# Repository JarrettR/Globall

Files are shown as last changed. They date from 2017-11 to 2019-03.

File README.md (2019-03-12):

Globall
================

### What's this?

This is a persistence-of-vision globe.

### What's that?

Persistence of vision is the phenomenon where something moving very fast appears to be an entire collection of objects. Generally involving light, it can fool our eyes into believing that we're seeing a single line of light when there's really only one, or a 2D image, when there's really only a single line of lights turning on and off quickly.

### Cool! How does that relate?

By arranging LEDs around a circle and spinning it very rapidly, an image can be created. The primary use-case of this repo is to create a globe (using green and blue LEDs), but it can easily be used for text or any other arbitrary image.

### Pictures

Mechanical, PCB, and spinning globe:

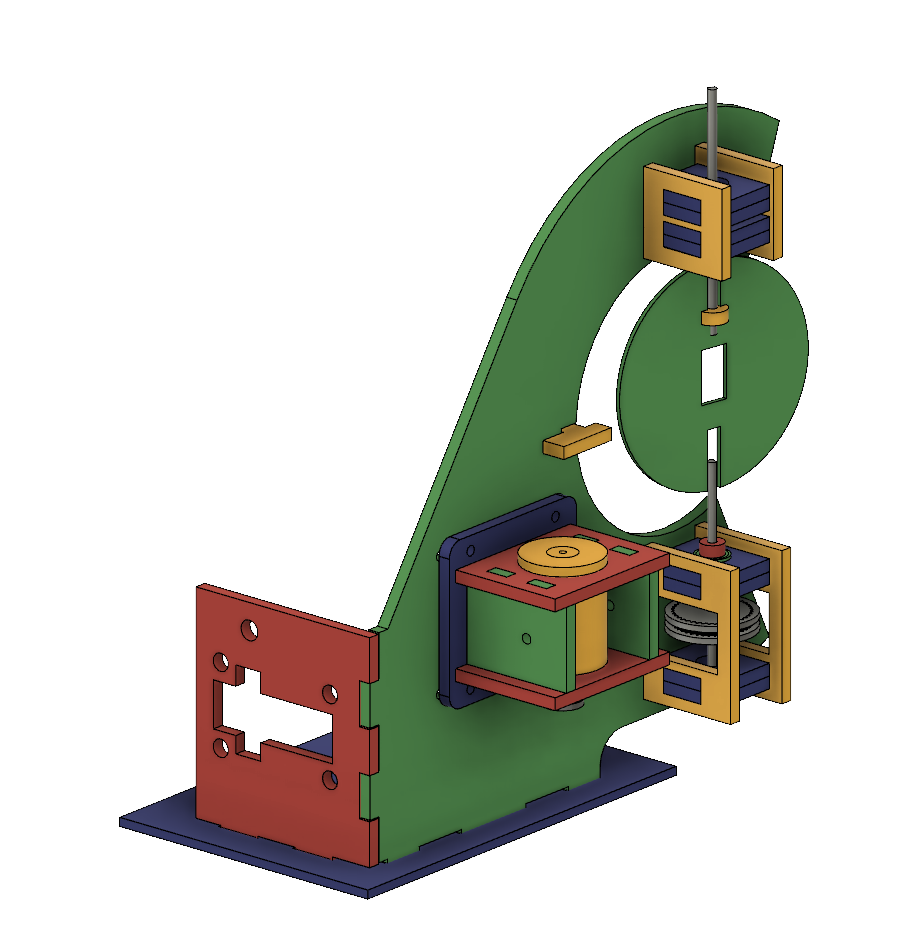
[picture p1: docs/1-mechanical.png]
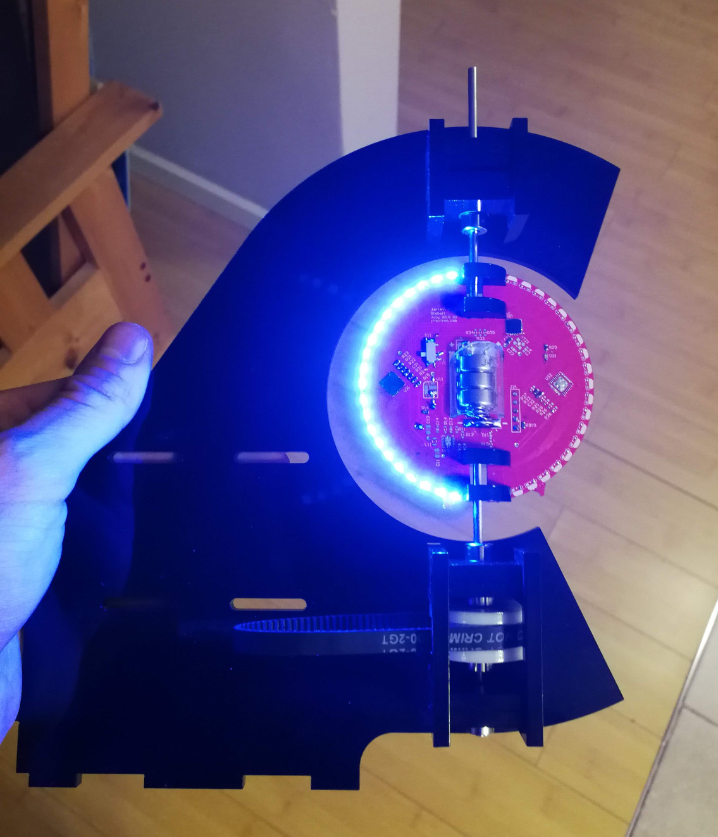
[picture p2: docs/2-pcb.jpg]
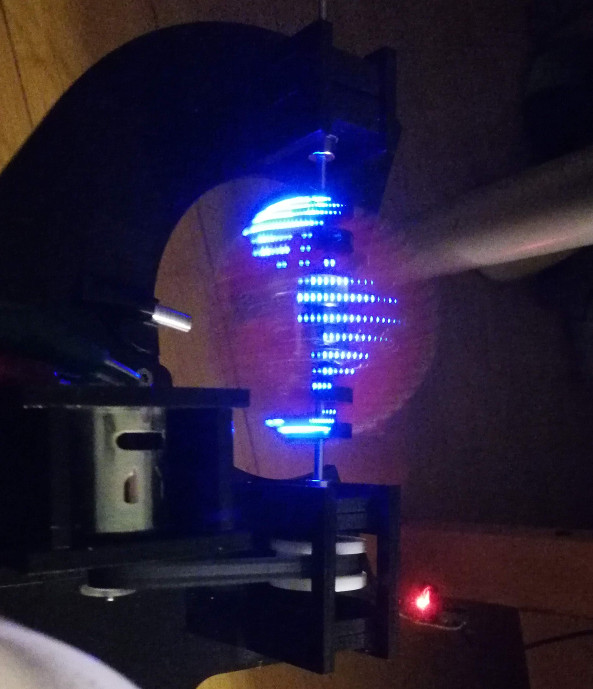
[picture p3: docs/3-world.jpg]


Pattern-making:

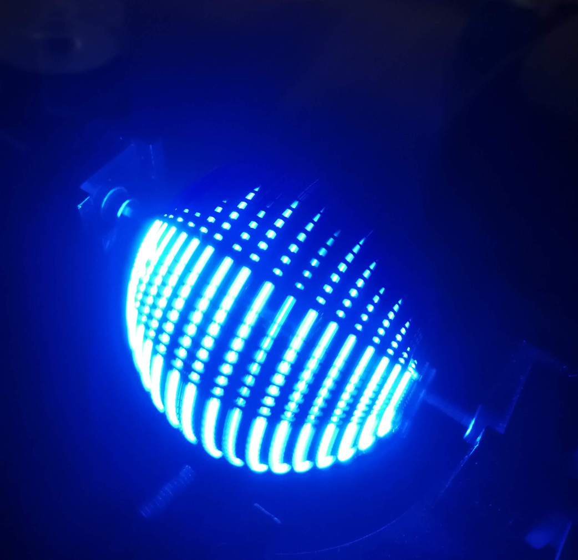
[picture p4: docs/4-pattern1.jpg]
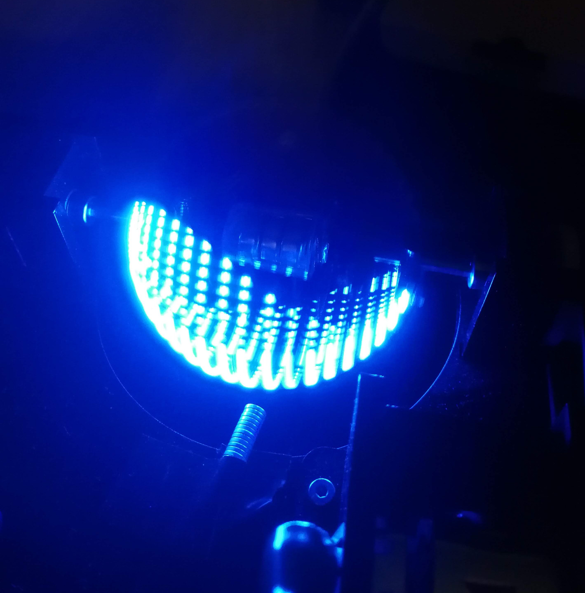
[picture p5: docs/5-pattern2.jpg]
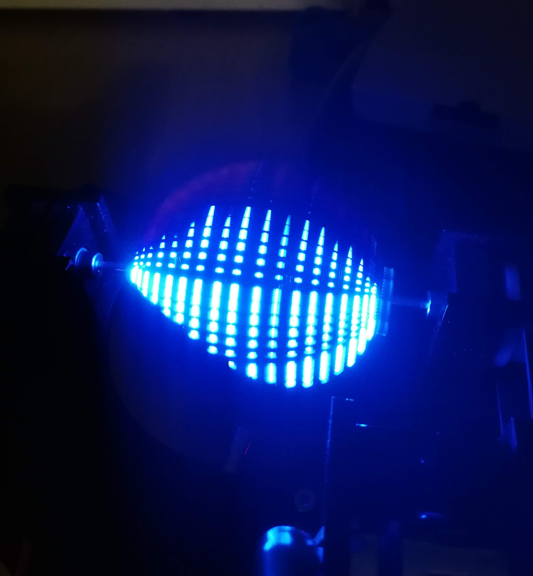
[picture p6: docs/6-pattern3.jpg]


### Status

This is under sporadic development.
The firmware is compilable, and it can generate passable images.
The PCB works, but will eventually go through a redesign. More LEDs, smaller LEDs, and a bunch of the power supply features can be stripped out.
The mechanical design has always been intended to be a minimum viable product, and is very functional. A redesign to make it prettier will eventually happen.
The image converter in the tools page might be useful for other POV systems at this change, check it out.

### Contributing

This is a (mostly) hardware project! I don't know what contributions are possible! Hardware pull requests are unlikely to be accepted, but give anything else a shot, I guess. I'm open to it.

### Useful takeaways

Check the `tools` folder for the Python tool I wrote to generate the image data. It should be fairly extentible to any projects that require displaying images programmatically.

### Further Reading

I have written a summary post about this on my website, [here](https://jrainimo.com/build/?p=1176).

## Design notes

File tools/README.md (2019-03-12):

Tools
================

## convert.py

### Usage

This is a tool that takes in image files, processes them, and then exports them into PNG, CSV, or C code formats.

First, install the only prerequisite, the Python Imaging Library:
`pip install pillow`
You might need to run that with `sudo` or as an administrator on Windows.

For this particular project, the command to generate the final files is:
` python convert.py -i World_map.png -t c -n -v -c blueMap -x 60 -y 20 -o blue `

Type `python convert.py --help` for full list of options. At present, this is the output:

```
> python convert.py --help

usage: convert.py [-h] [-x WIDTH] [-y HEIGHT] [-i INPUT] [-o OUTPUT] [-t TYPE]
                  [-n] [-c CONST] [-f] [-l] [-v]

optional arguments:
  -h, --help            show this help message and exit
  -x WIDTH, --width WIDTH
                        Pixel density horizontal
  -y HEIGHT, --height HEIGHT
                        Pixel density vertical
  -i INPUT, --input INPUT
                        Input file
  -o OUTPUT, --output OUTPUT
                        Output file, no extension
  -t TYPE, --type TYPE  Output format(csv, png, or c)
  -n, --invert          Invert pixel weight
  -c CONST, --const CONST
                        (C output only) Const var name
  -f, --fragmented      Split up data for fragmented memory
  -l, --large           Larger, 12-bit pixels
  -v, --verbose         Print out internal variables
```

This was intended to be reusable, and is fairly robust.

It should take any image format and convert it to greyscale, although different formats have not been tested exhaustively. PNG files work well.

For this project, sensible defaults (and the ones included in the firmware) are generated using `./gen.sh`

### Sample Inputs

These are some good images for testing various setups.

#### simple.png

simple

Simple, small image of multiple colours, intended to test the conversion process only.

#### scrolltest.png

scrolltest

A human-recognisable pattern to easily check correct pixel order on the physical test bench.

#### cycle.png

cycle

A similar human-recognisable pattern to the above.

#### right-align.png and left-align.png

left-align

right-align

With one of these on each side, tests the code speed and maximum input frequency.
At a comfortable speed, all LEDs on both sides will be blinking. As soon as speed increases enough that the processor is no longer able to keep up, half of one or both sides will start sticking. As the input pulses is fed in faster, the LEDs will stop working entirely.

This is a quick way to tune for "max frequency".

#### World_map.png

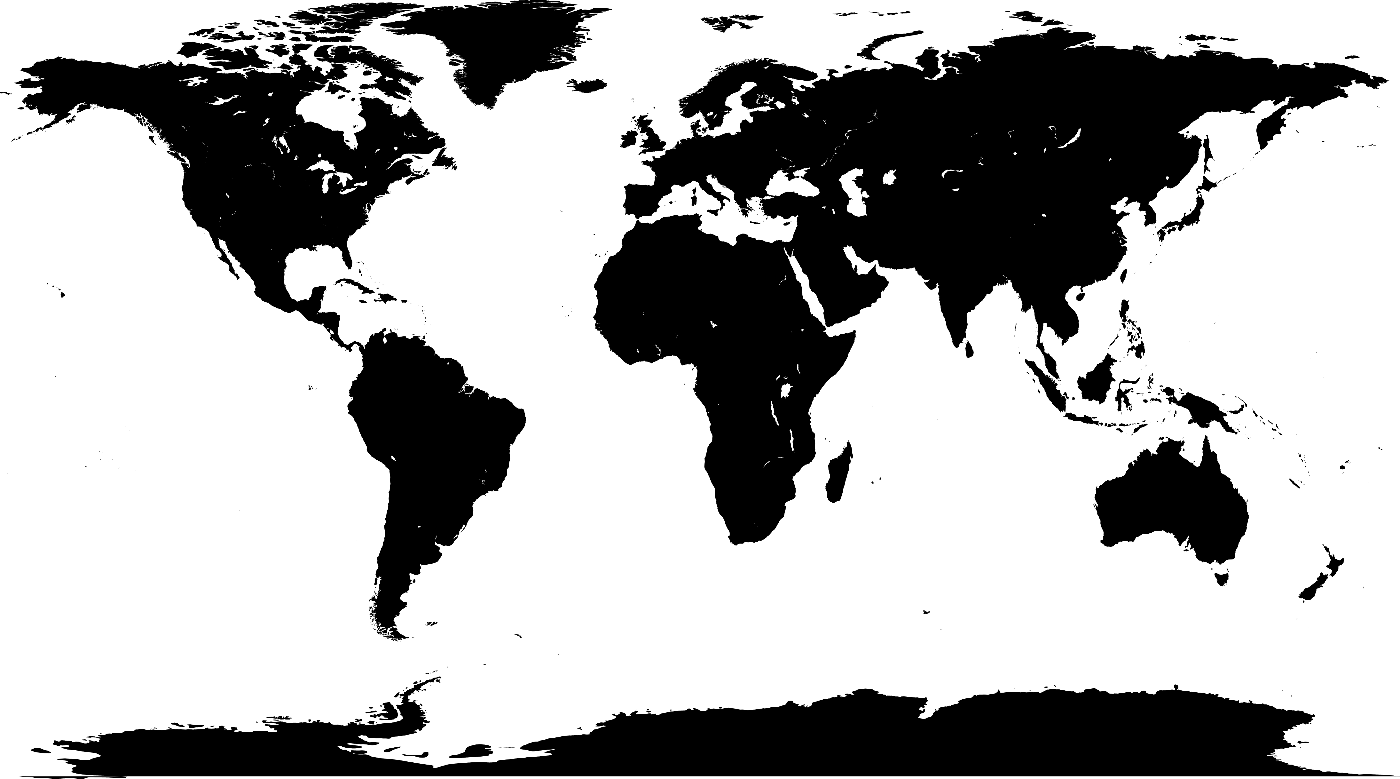
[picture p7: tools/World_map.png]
World_map


The goal.

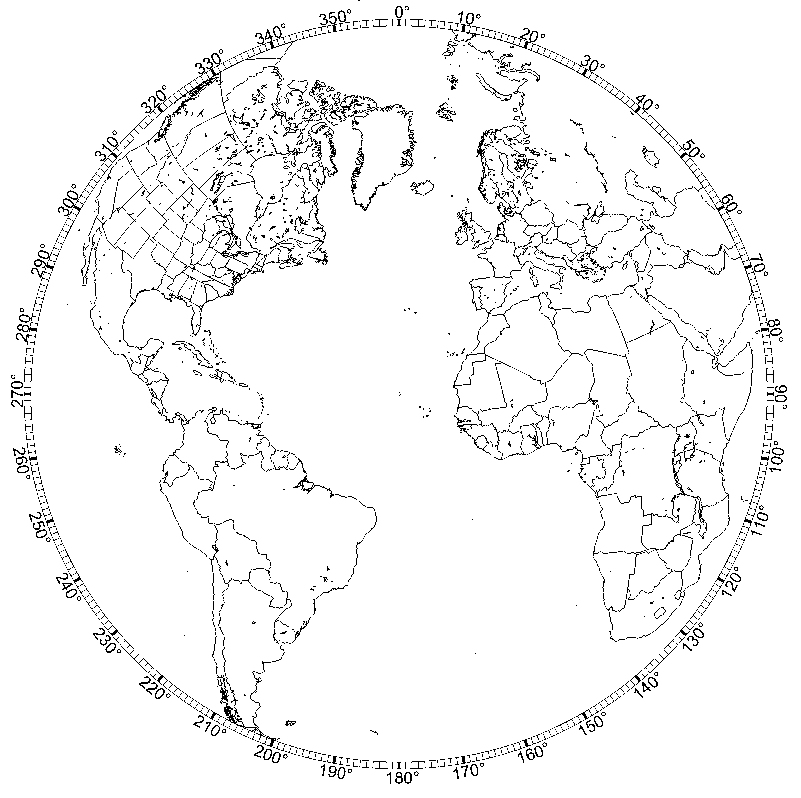
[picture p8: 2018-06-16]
Hardware/R1/AzimuthalMap2.bmp

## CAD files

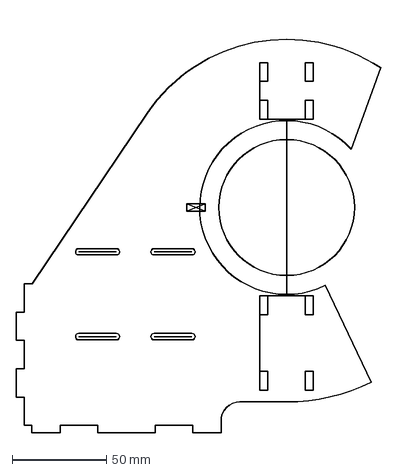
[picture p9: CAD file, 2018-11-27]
Mechanical/R1/DXFs/1 - Main Plate.dxf
193.0 x 220.9 mm

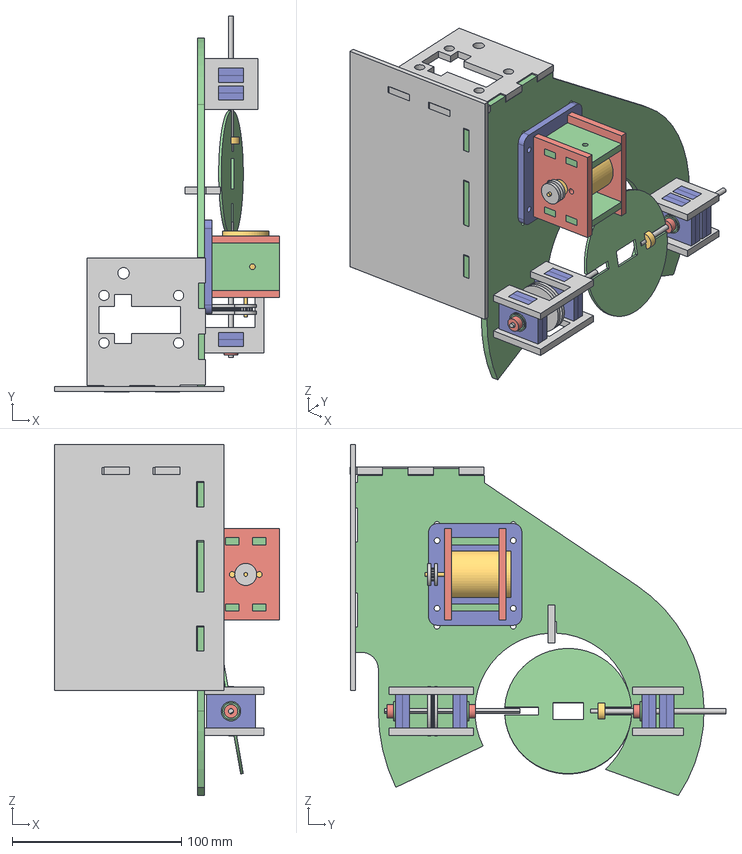
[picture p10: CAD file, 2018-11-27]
Mechanical/R1/DXFs/Main Assembly.step
132.9 x 221.9 x 207.2 mm
Bearing Side Plate x 2
Main Plate
Bearing holder x 8
Driven Pulley 40t
D-Shaft x 2
PCB
DC Motor
Motor Pulley
Motor mount plate
Motor Back Plate
Motor Bottom Plate
Motor Side Plate x 2
Bearing Long Side Plate x 2
623ZZ Flanged x 3
3mm Shaft Collar x 3
Shaft Coupler
base
Magnet Holder
Base Support

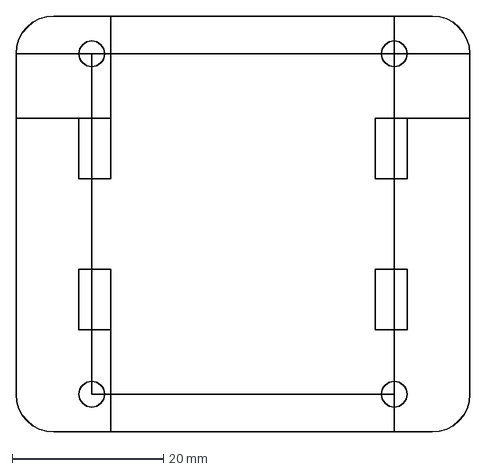
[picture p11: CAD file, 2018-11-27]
Mechanical/R1/DXFs/1 - Motor Bottom Plate.dxf
60.0 x 55.0 mm

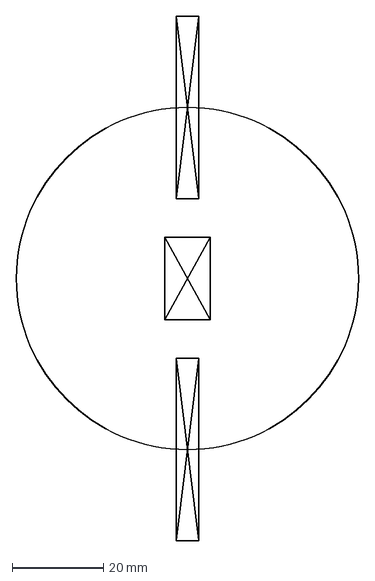
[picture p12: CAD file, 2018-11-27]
Mechanical/R1/DXFs/1 - PCB.dxf
75.0 x 115.0 mm

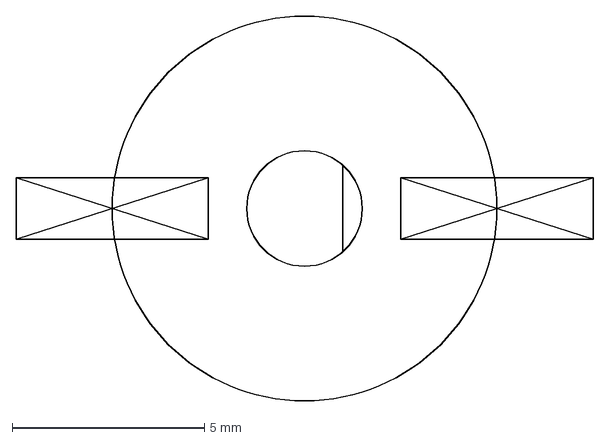
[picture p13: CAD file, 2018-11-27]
Mechanical/R1/DXFs/4 - Shaft Coupler.dxf
15.0 x 10.0 mm

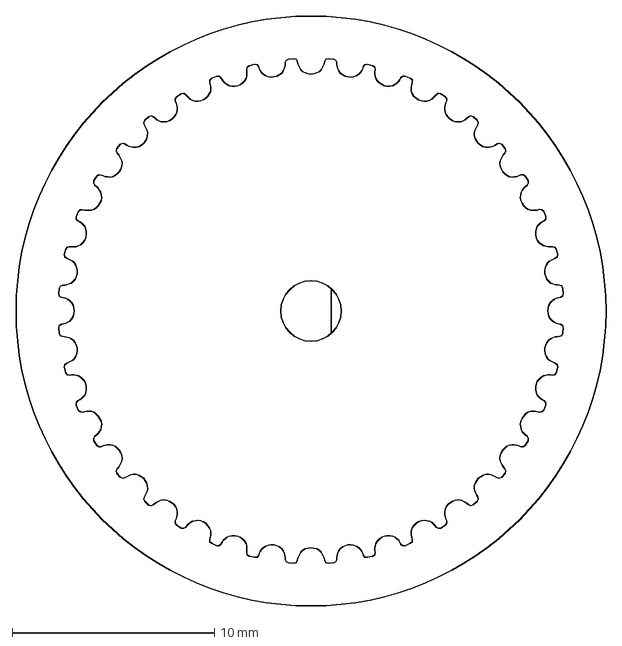
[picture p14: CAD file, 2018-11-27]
Mechanical/R1/DXFs/2 - Driven Pulley.dxf
29.1 x 29.1 mm

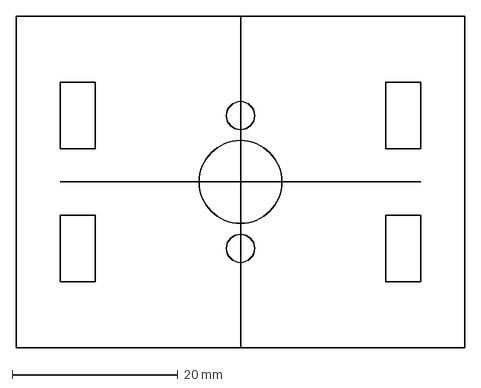
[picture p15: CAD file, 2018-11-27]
Mechanical/R1/DXFs/1 - Motor Mount Plate.dxf
54.0 x 40.0 mm

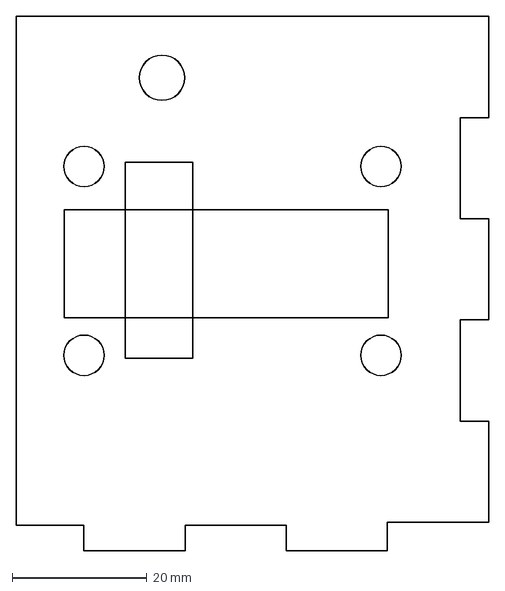
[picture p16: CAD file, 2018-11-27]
Mechanical/R1/DXFs/1 - Base Support.dxf
70.0 x 79.2 mm

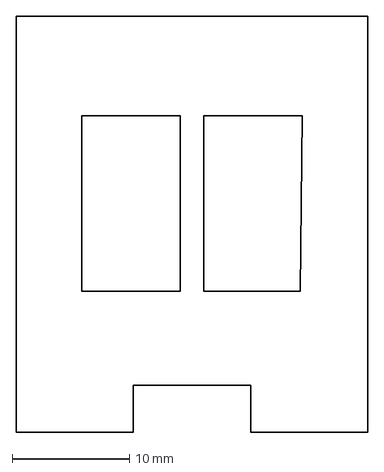
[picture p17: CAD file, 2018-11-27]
Mechanical/R1/DXFs/2 - Bearing Side Plater.dxf
30.0 x 35.5 mm

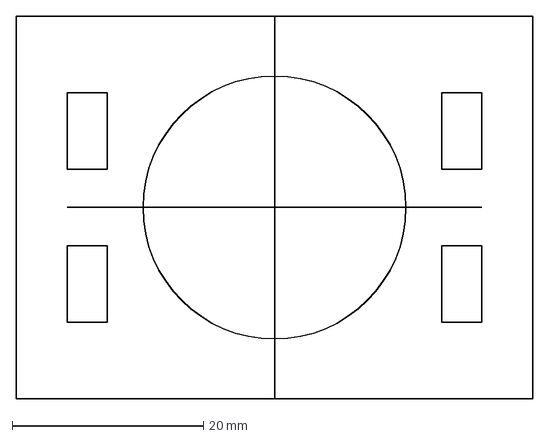
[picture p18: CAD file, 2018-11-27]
Mechanical/R1/DXFs/1 - Motor Back Plate.dxf
54.0 x 40.0 mm

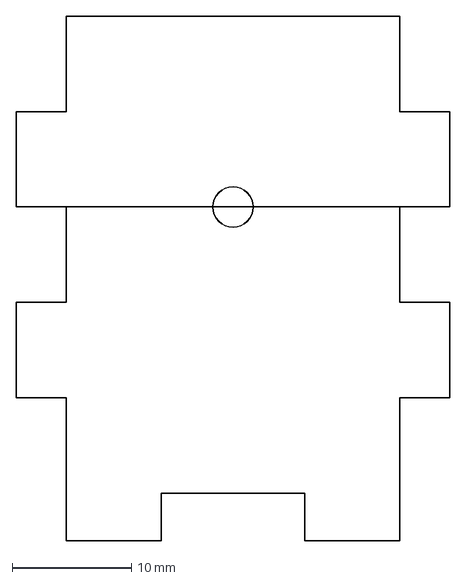
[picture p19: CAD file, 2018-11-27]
Mechanical/R1/DXFs/2 - Motor Side Plate.dxf
36.4 x 44.0 mm

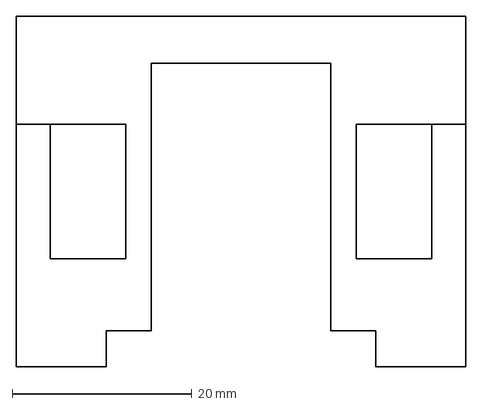
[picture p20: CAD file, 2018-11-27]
Mechanical/R1/DXFs/2 - Bearing Long Side Plate.dxf
50.0 x 39.0 mm

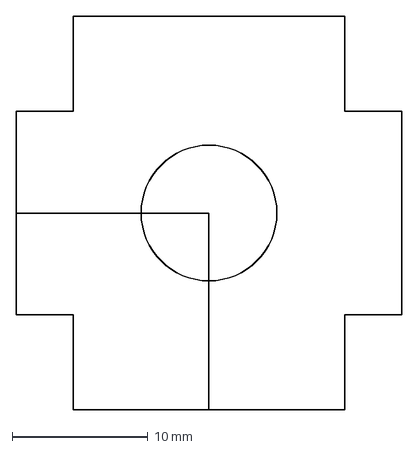
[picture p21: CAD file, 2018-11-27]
Mechanical/R1/DXFs/8 - Bearing Holder.dxf
28.4 x 29.0 mm

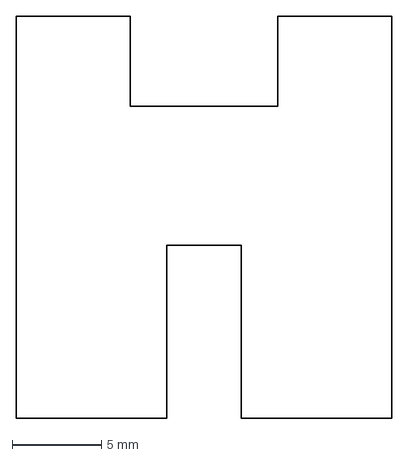
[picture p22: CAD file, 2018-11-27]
Mechanical/R1/DXFs/1 - Magnet Holder.dxf
21.0 x 22.5 mm

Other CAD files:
Mechanical/R1/DXFs/2 - Motor Pulley.dxf

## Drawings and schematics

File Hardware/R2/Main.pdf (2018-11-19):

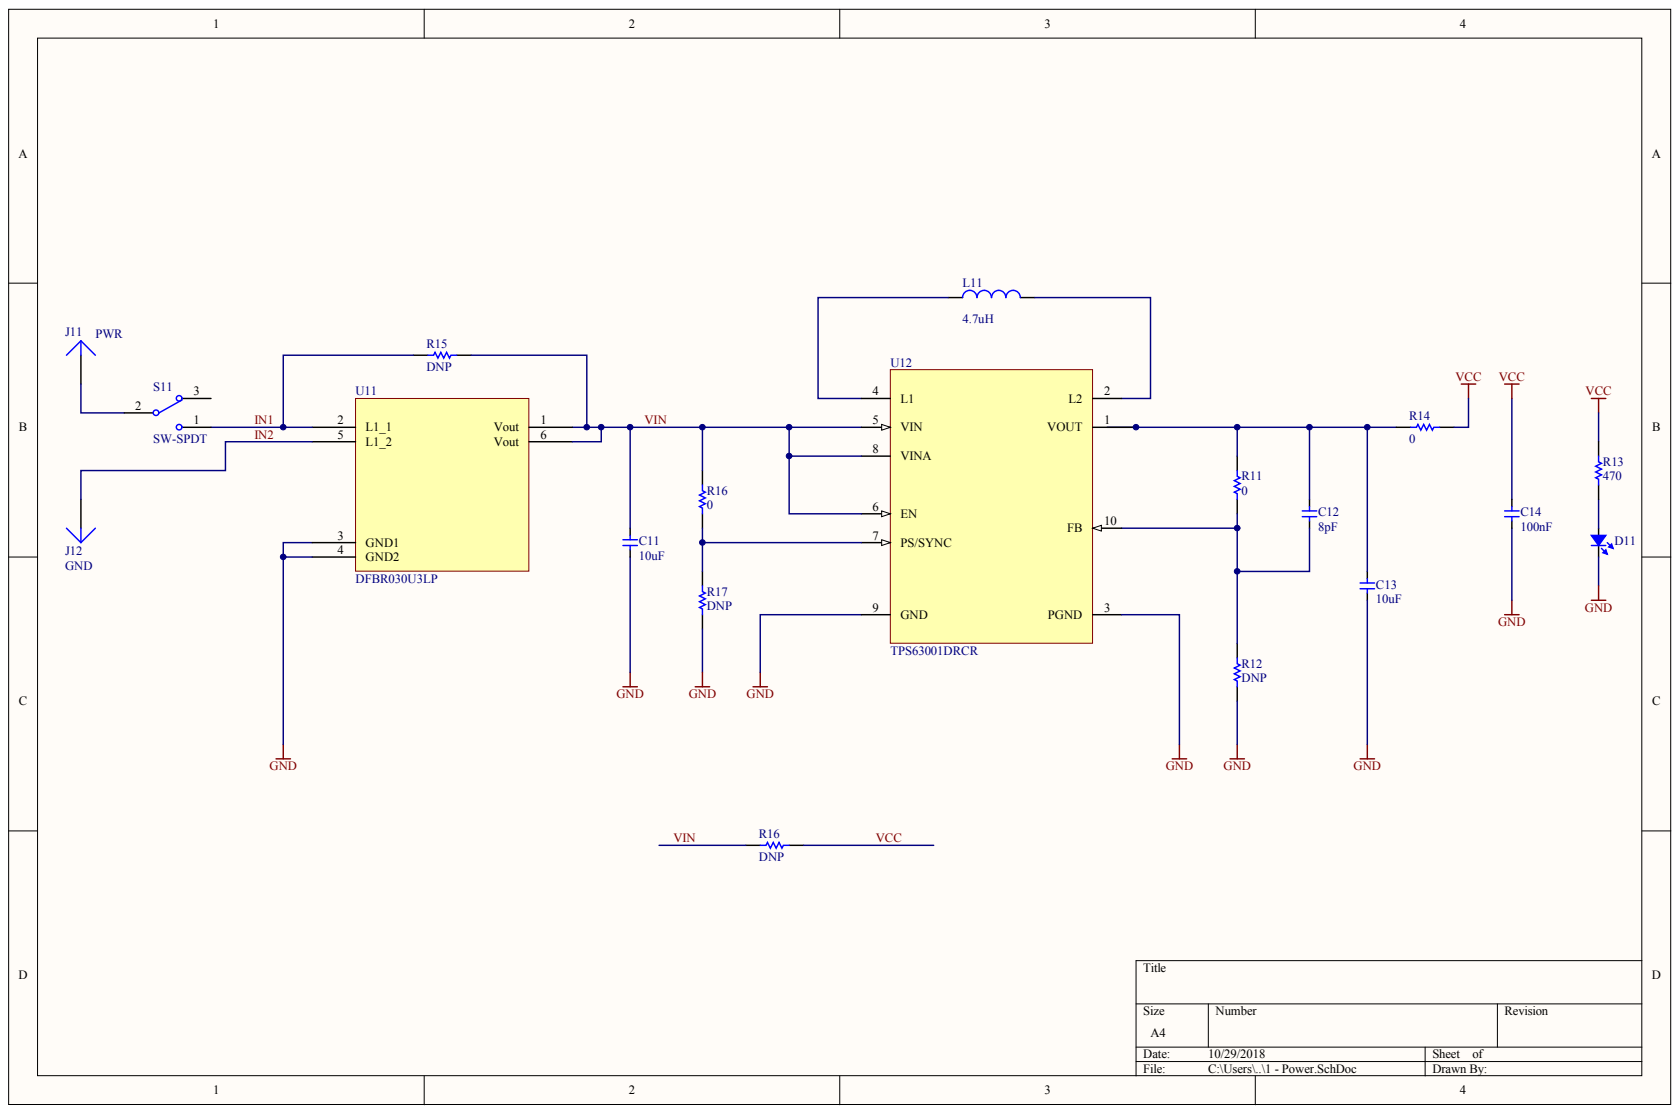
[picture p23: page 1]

Si z e A 4 | Numbe r | Rev isi o n

Date : 10/29/201 8 | Sh eet o f
Fi l e : C:\Users\..\1 - Power.SchDo c | Drawn By :

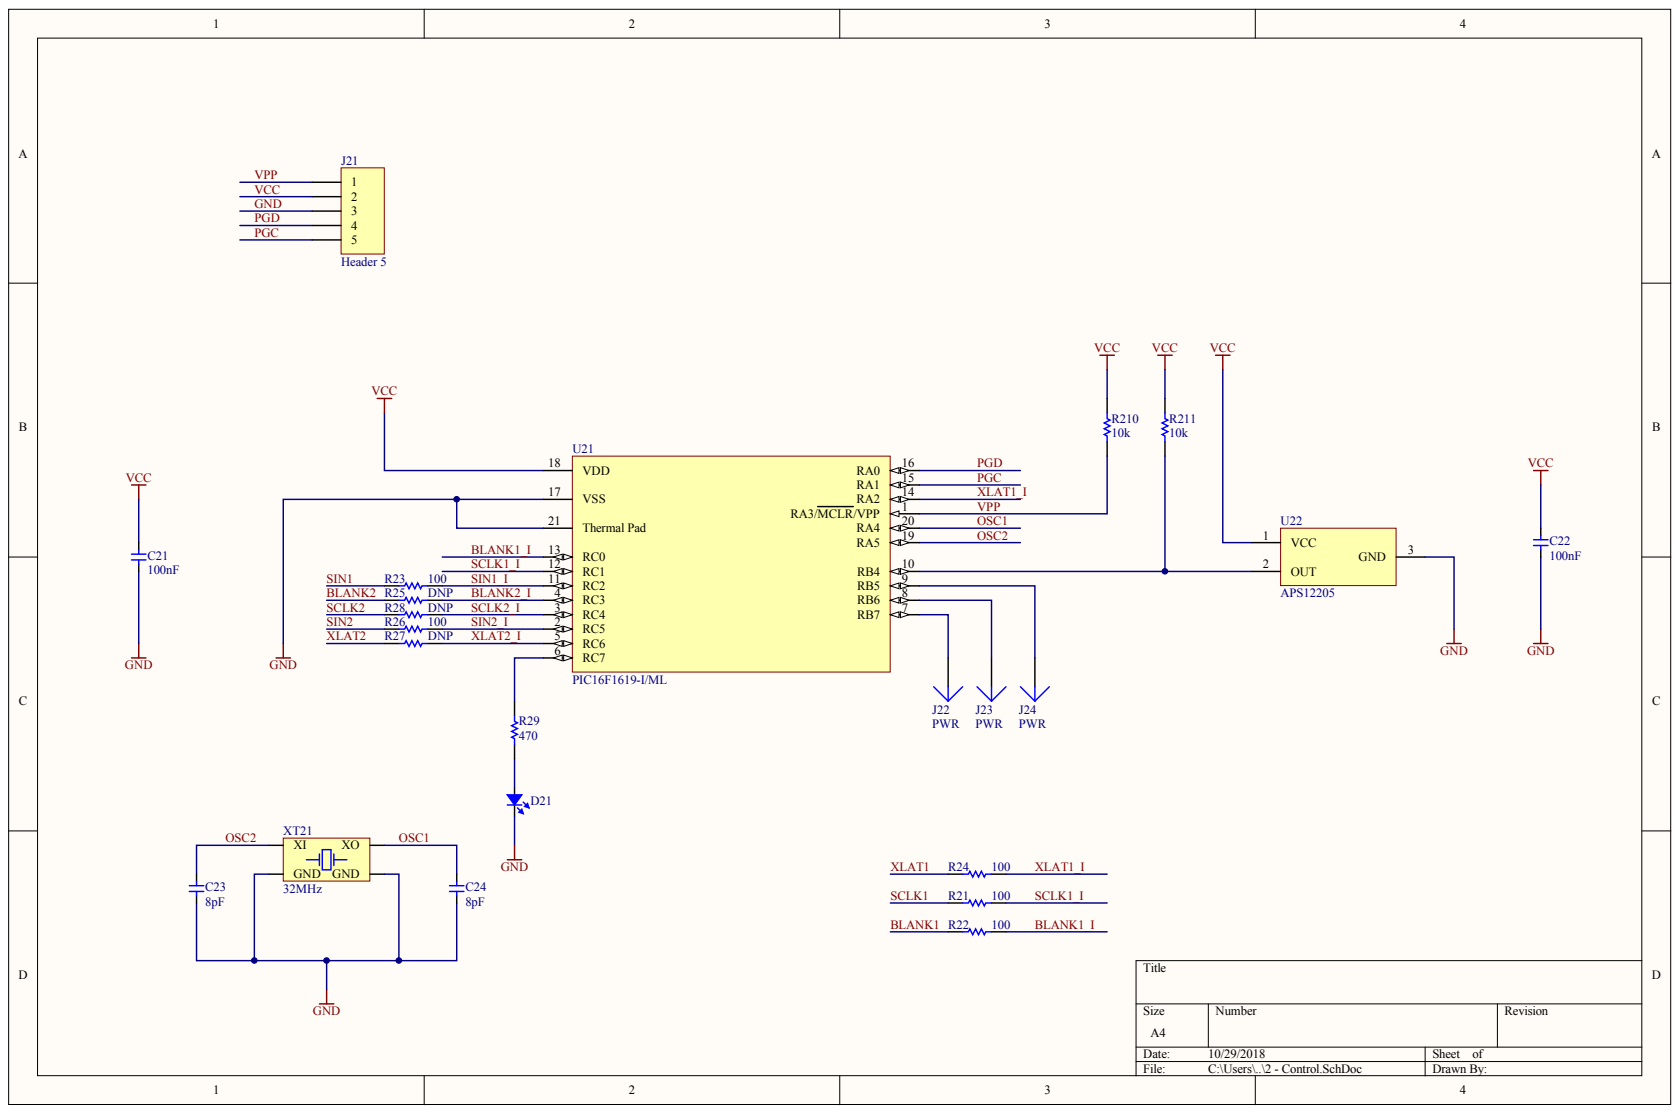
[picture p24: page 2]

Date : 10/29/201 8 | Sh eet o f
Fi l e : C:\Users\..\2 - Co ntro l.Sc hDo c | Drawn By :

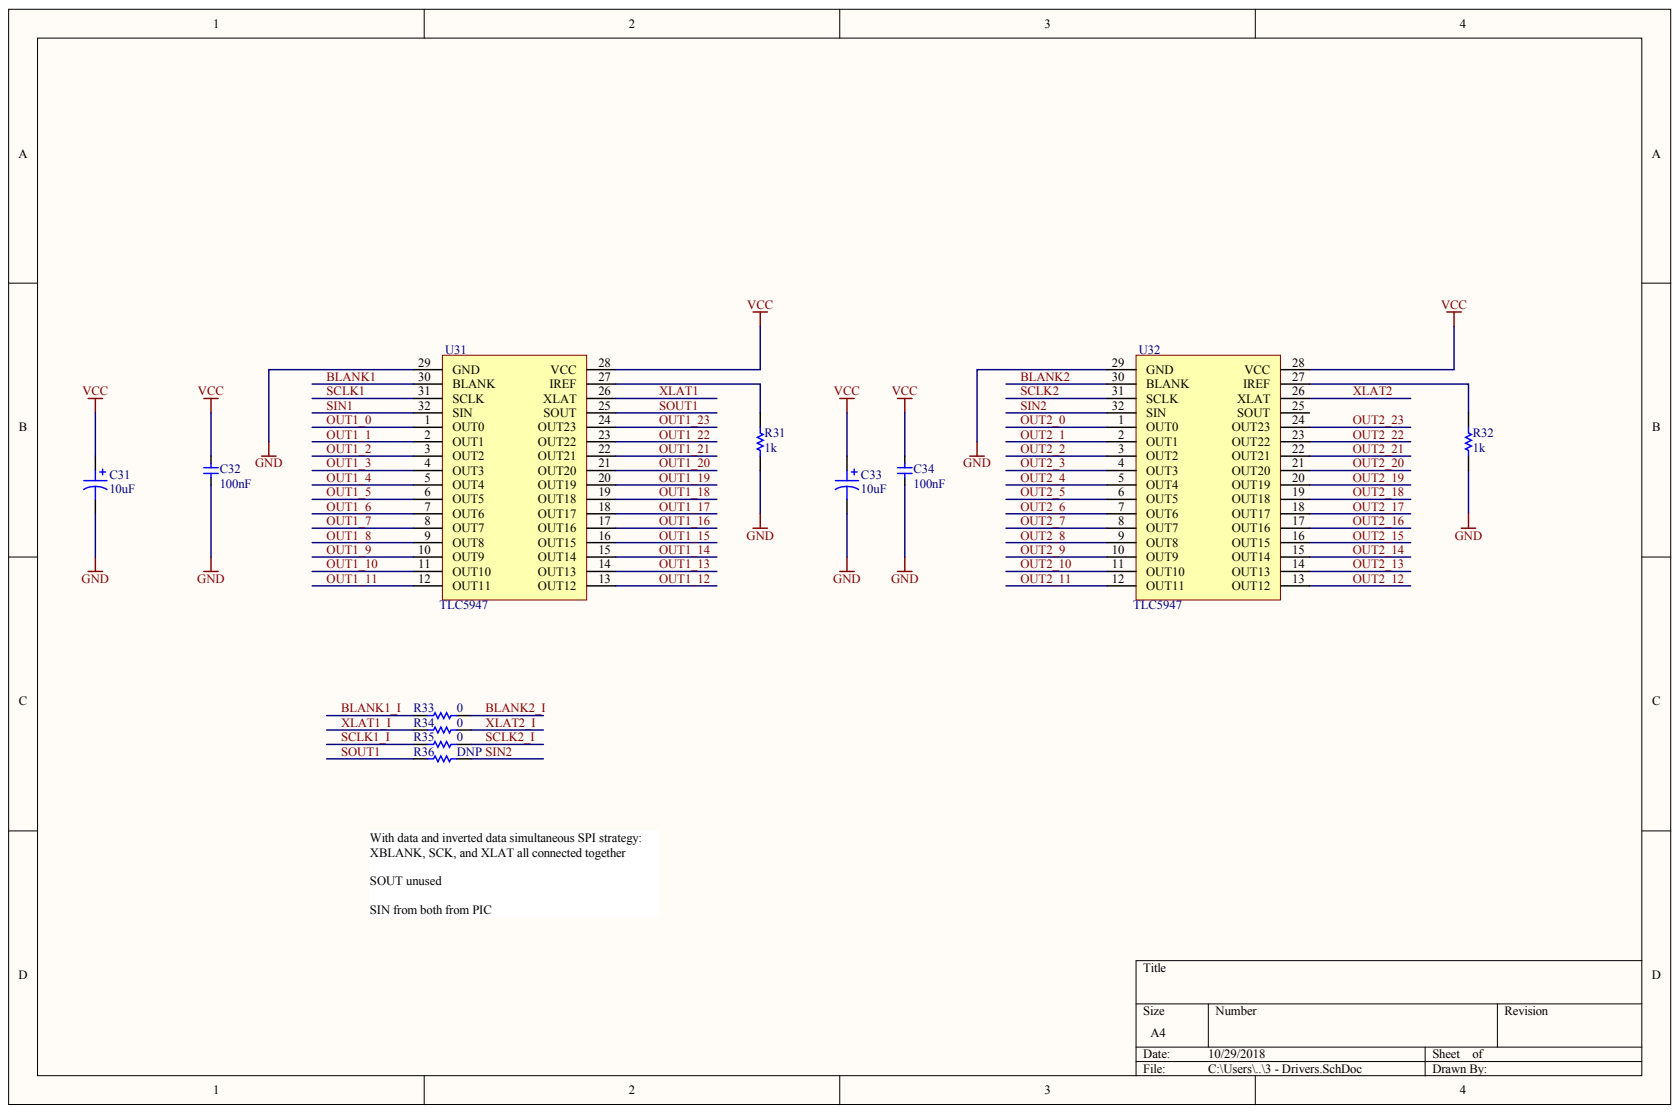
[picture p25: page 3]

Si z e A 4 | Numbe r | Rev isi o n

Date : 10/29/201 8 | Sh eet o f
Fi l e : C:\Users\..\3 - Dri v ers.Sc hDo c | Drawn By :

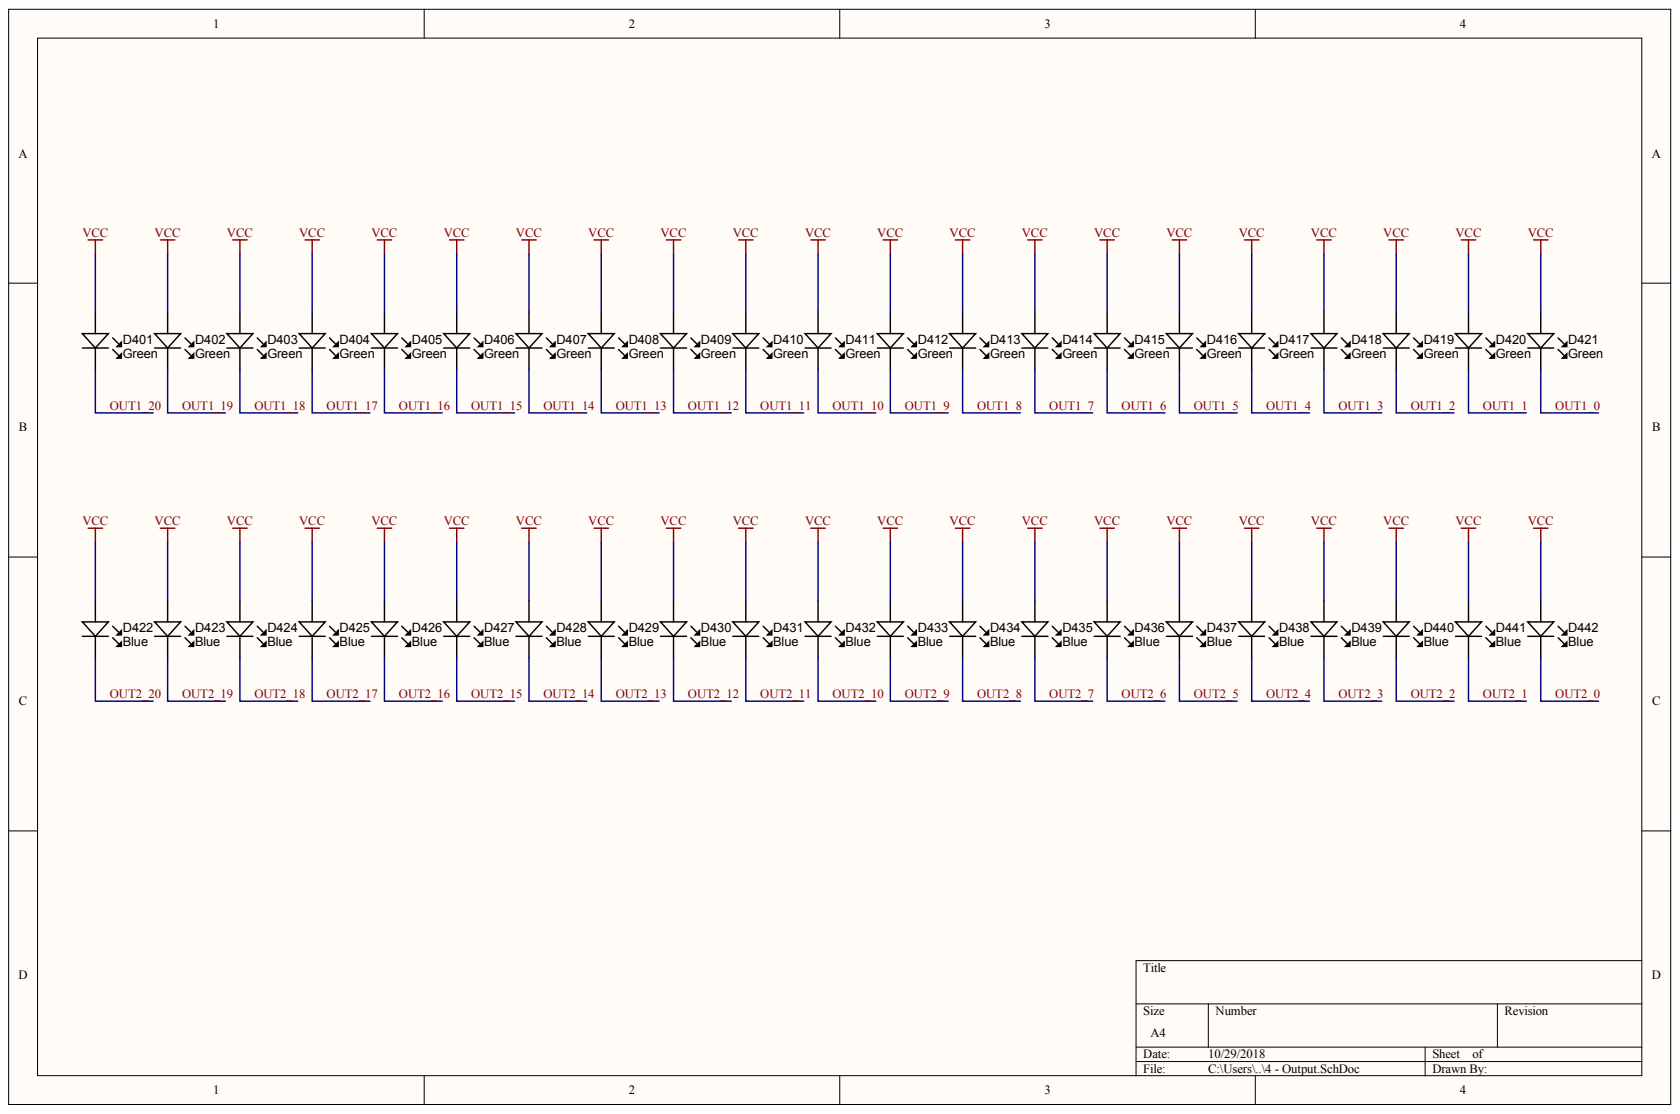
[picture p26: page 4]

Size A4 | Number | Revision

Date: 10/29/2018 | Sheet of
File: C:\Users\..\4 - Output.SchDoc | Drawn By:

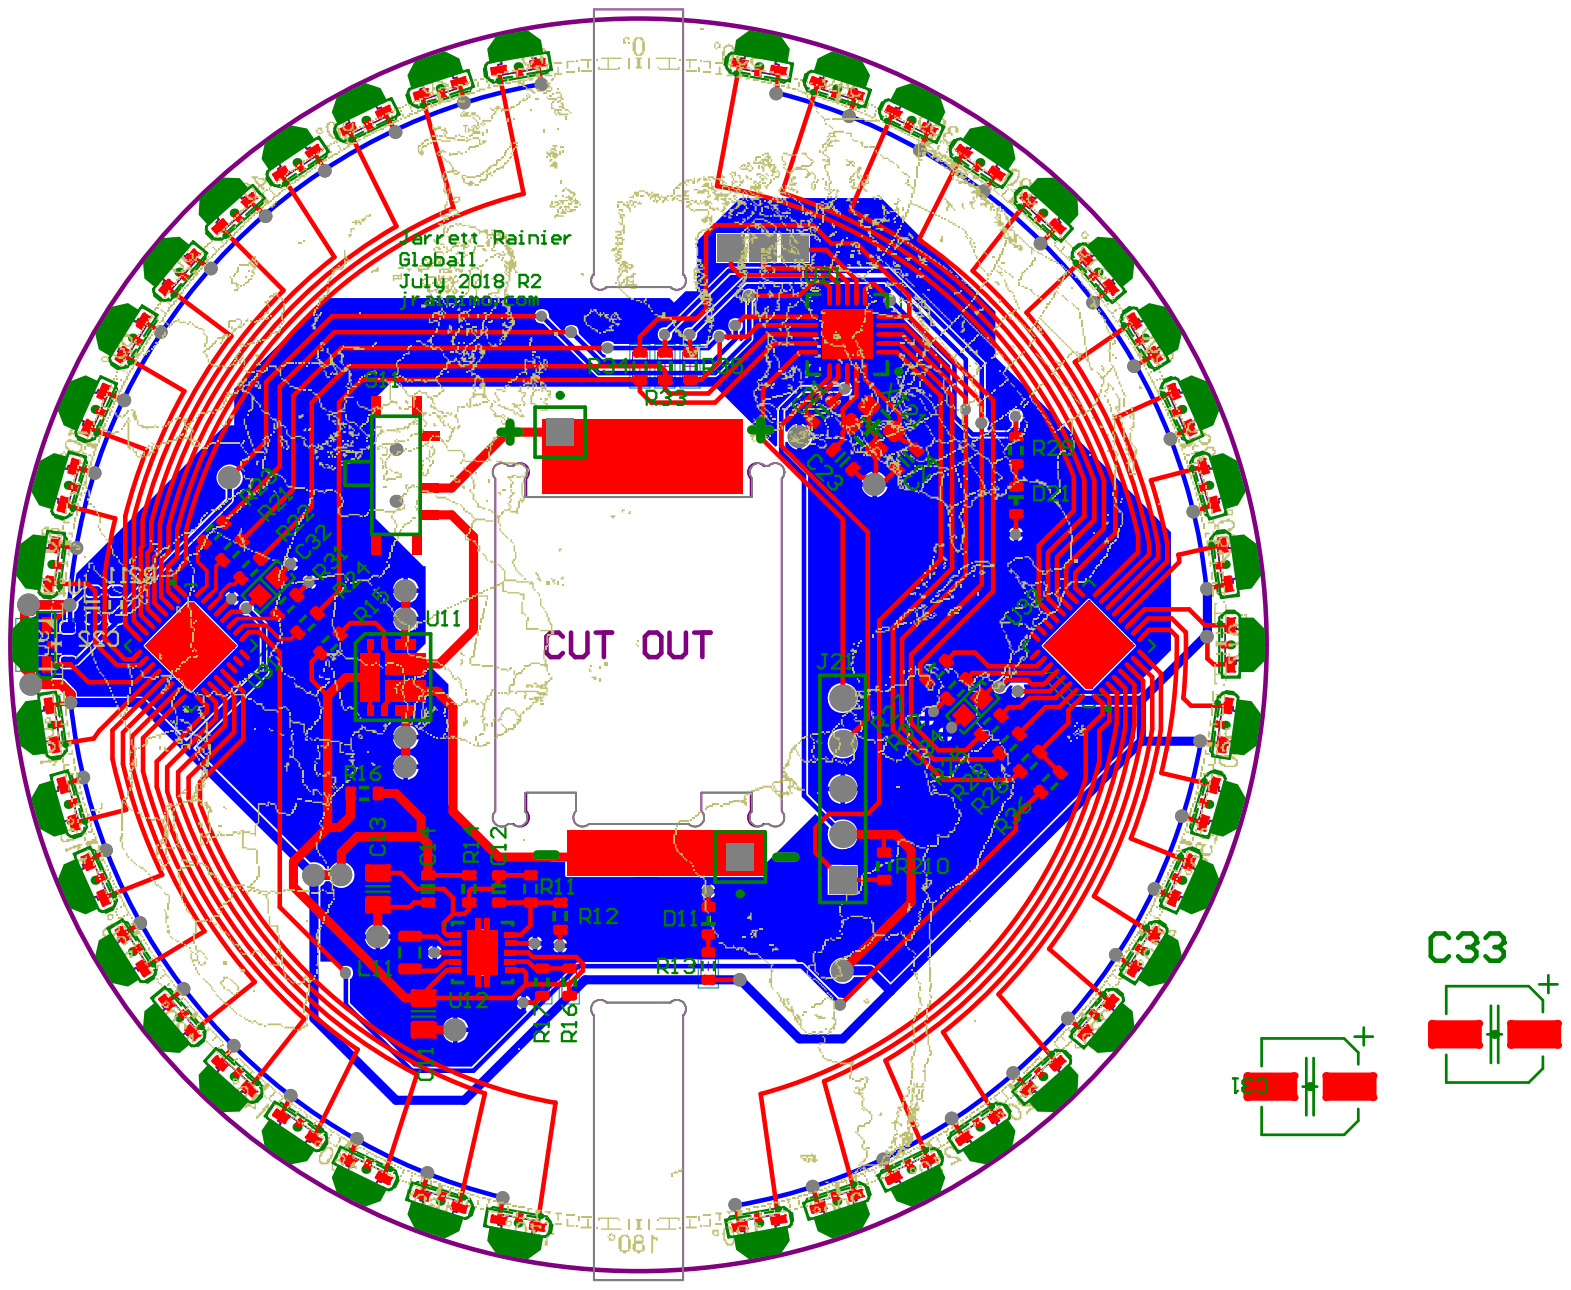
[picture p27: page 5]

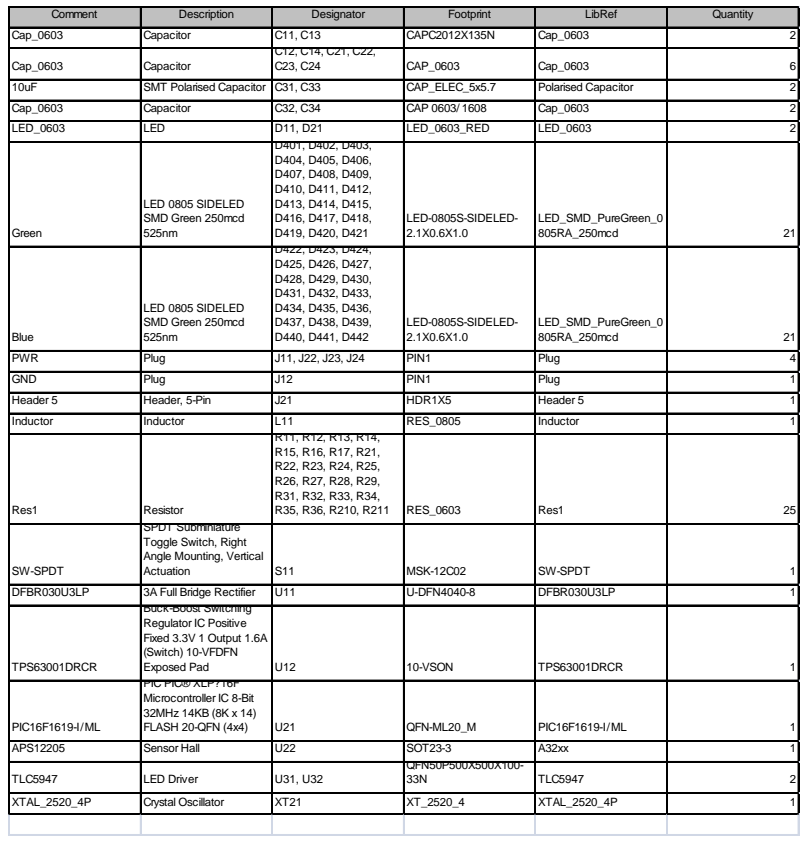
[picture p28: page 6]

Comment | Description | Designator | Footprint | LibRef | Quantity
Cap_0603 | Capacitor | C11, C13 | CAPC2012X135N | Cap_0603 | 2
Cap_0603 | Capacitor | C12, C14, C21, C22, C23, C24 | CAP_0603 | Cap_0603 | 6

10uF | SMT Polarised Capacitor | C31, C33 | CAP_ELEC_5x5.7 | Polarised Capacitor | 2
Cap_0603 | Capacitor | C32, C34 | CAP 0603/ 1608 | Cap_0603 | 2
LED_0603 | LED | D11, D21 | LED_0603_RED | LED_0603 | 2
Green | LED 0805 SIDELED SMD Green 250mcd 525nm | D401, D402, D403, D404, D405, D406, D407, D408, D409, D410, D411, D412, D413, D414, D415, D416, D417, D418, D419, D420, D421 | LED-0805S-SIDELED-2.1X0.6X1.0 | LED_SMD_PureGreen_0 805RA_250mcd | 21

Blue | LED 0805 SIDELED SMD Green 250mcd 525nm | D422, D423, D424, D425, D426, D427, D428, D429, D430, D431, D432, D433, D434, D435, D436, D437, D438, D439, D440, D441, D442 | LED-0805S-SIDELED-2.1X0.6X1.0 | LED_SMD_PureGreen_0 805RA_250mcd | 21

PWR | Plug | J11, J22, J23, J24 | PIN1 | Plug | 4
GND | Plug | J12 | PIN1 | Plug | 1
Header 5 | Header, 5-Pin | J21 | HDR1X5 | Header 5 | 1
Inductor | Inductor | L11 | RES_0805 | Inductor | 1
Res1 | Resistor | R11, R12, R13, R14, R15, R16, R17, R21, R22, R23, R24, R25, R26, R27, R28, R29, R31, R32, R33, R34, R35, R36, R210, R211 | RES_0603 | Res1 | 25

SW-SPDT | SPDT Subminiature Toggle Switch, Right Angle Mounting, Vertical Actuation | S11 | MSK-12C02 | SW-SPDT | 1

DFBR030U3LP | 3A Full Bridge Rectifier | U11 | U-DFN4040-8 | DFBR030U3LP | 1
TPS63001DRCR | Buck-Boost Switching Regulator IC Positive Fixed 3.3V 1 Output 1.6A (Switch) 10-VFDFN Exposed Pad | U12 | 10-VSON | TPS63001DRCR | 1

PIC16F1619-I/ML | PIC PIC® XLP? 16F Microcontroller IC 8-Bit 32MHz 14KB (8K x 14) FLASH 20-QFN (4x4) | U21 | QFN-ML20_M | PIC16F1619-I/ML | 1

APS12205 | Sensor Hall | U22 | SOT23-3 | A32xx | 1
TLC5947 | LED Driver | U31, U32 | QFN50P500X500X100-33N | TLC5947 | 2

XTAL_2520_4P | Crystal Oscillator | XT21 | XT_2520_4 | XTAL_2520_4P | 1

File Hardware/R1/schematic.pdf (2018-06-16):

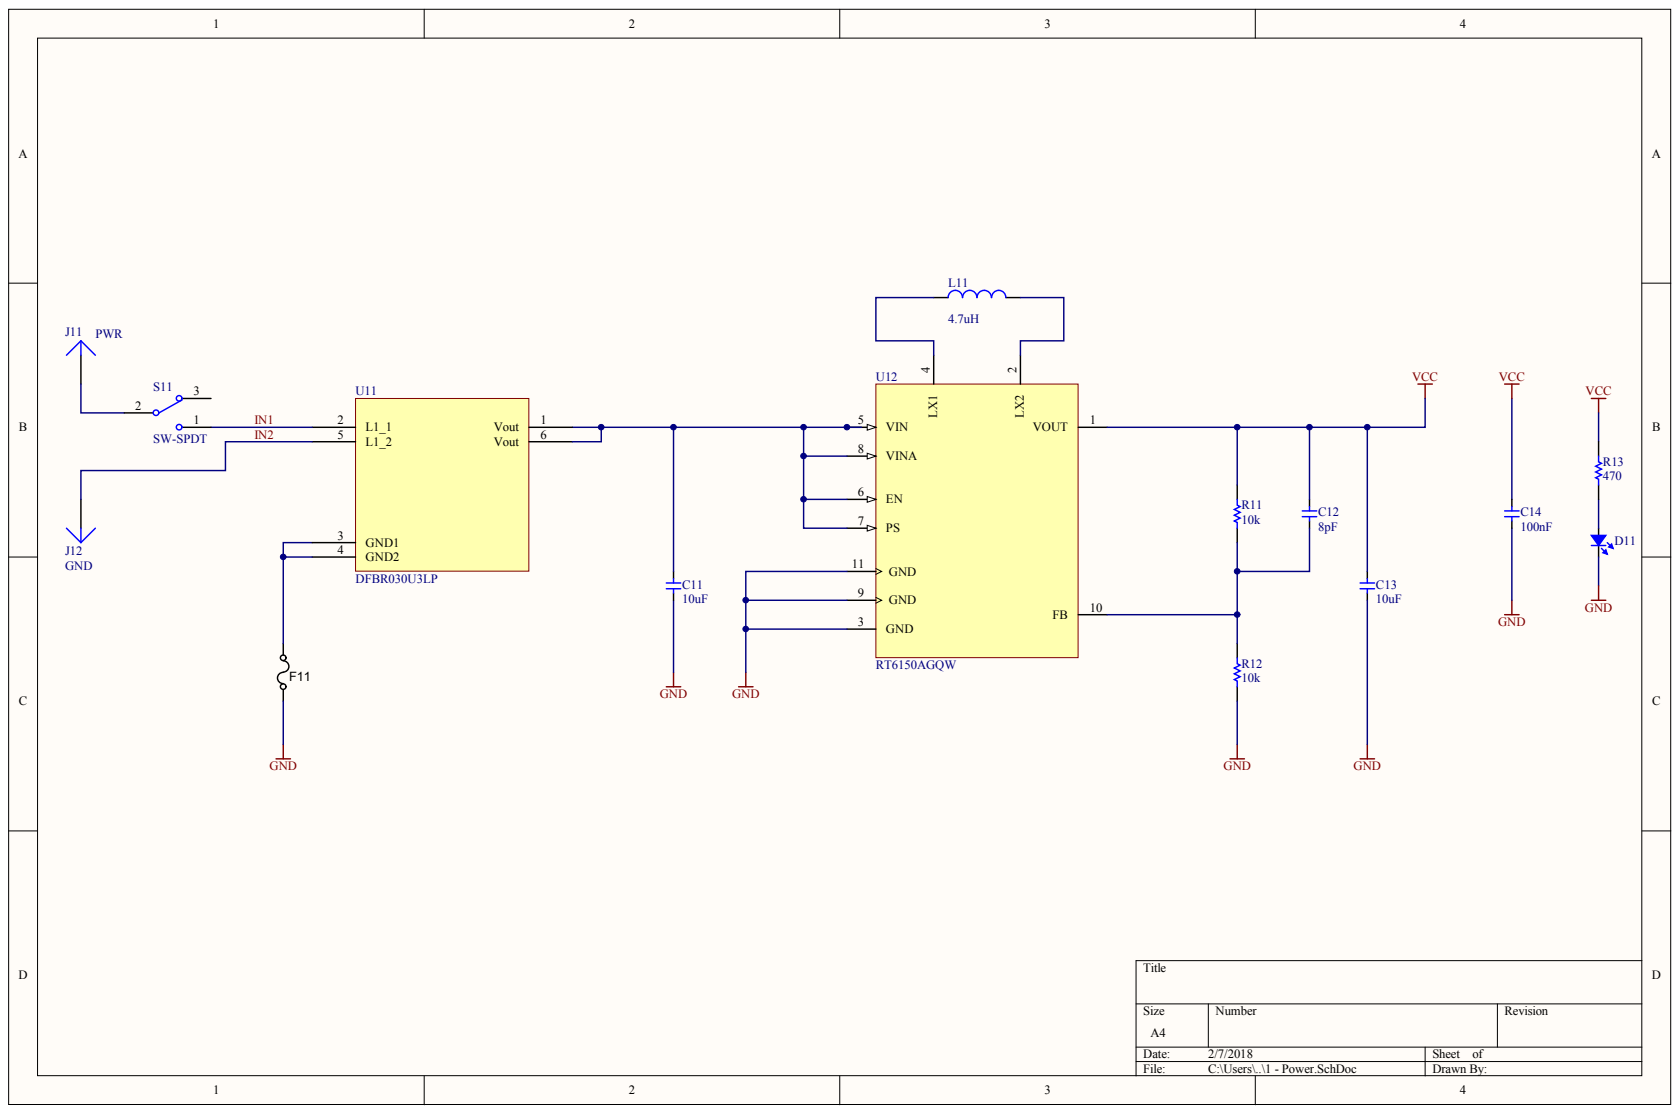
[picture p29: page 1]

7 | R11 10 k

Si z e A 4 | Numbe r | Rev isi o n

Date : 2/7/2018 | Sh eet o f
Fi l e : C:\Users\..\1 - Power.SchDo c | Drawn By :

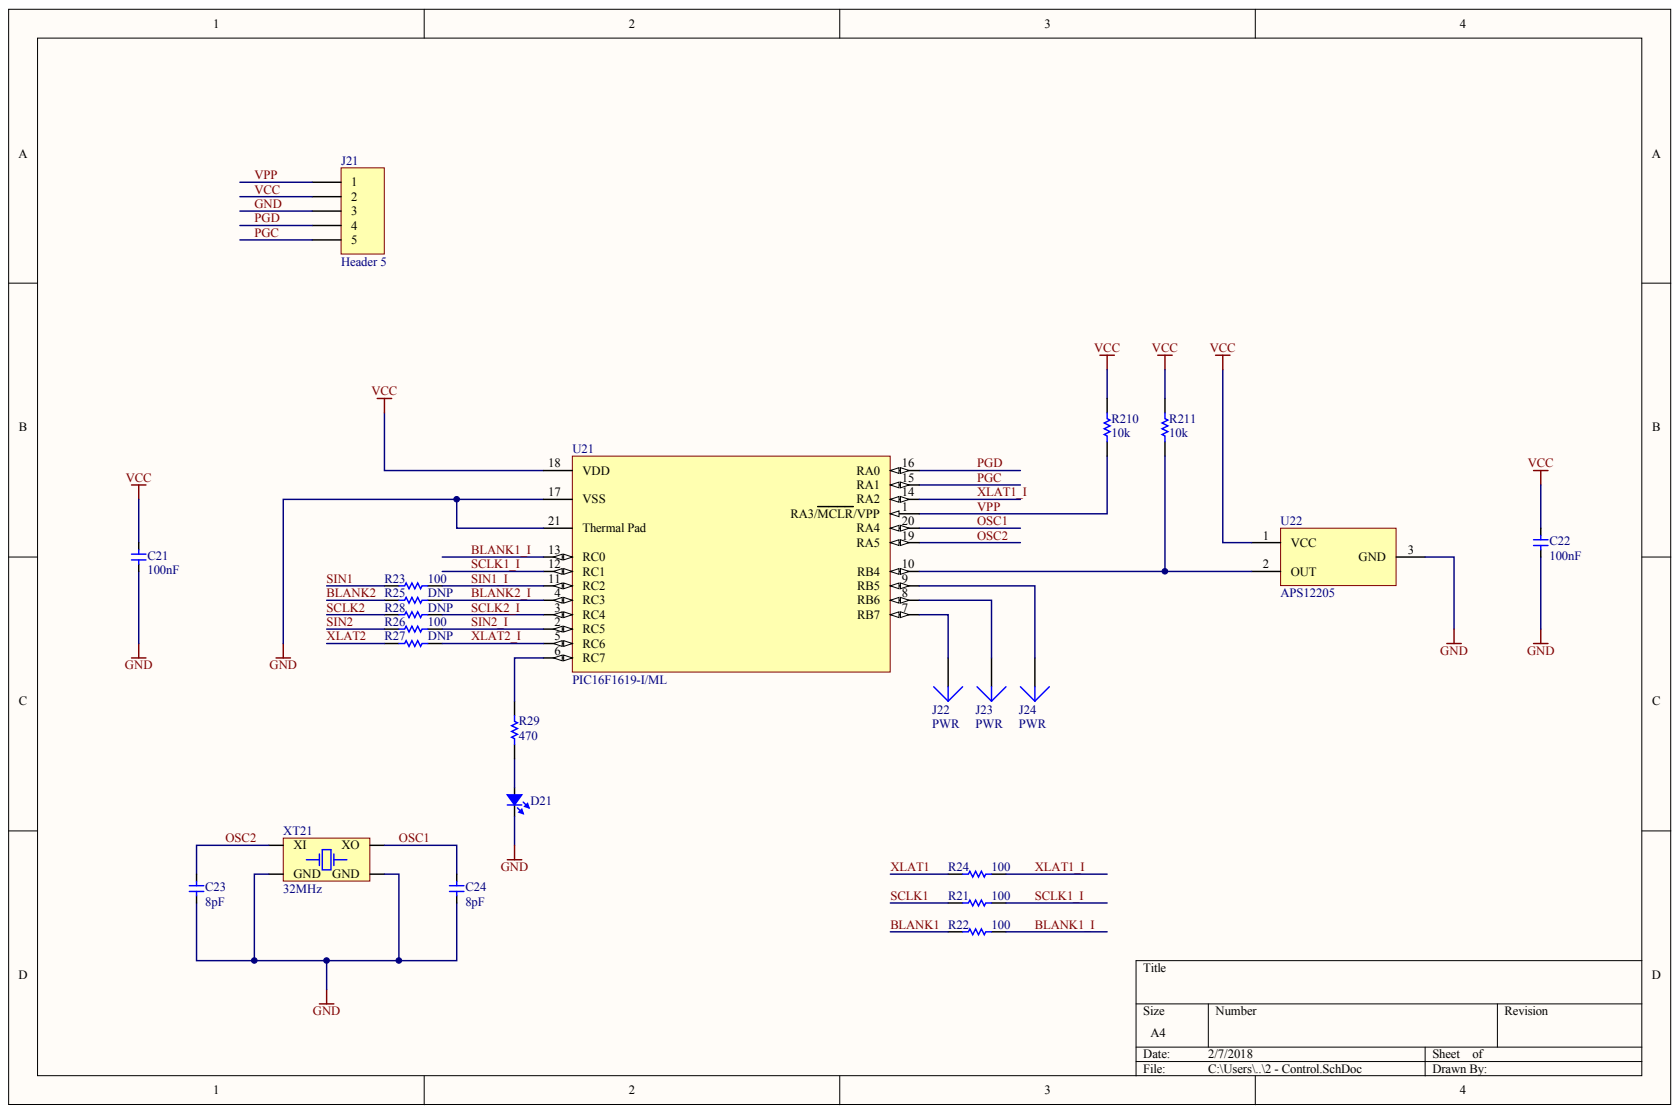
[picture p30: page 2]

Date : 2/7/2018 | Sh eet o f
Fi l e : C:\Users\..\2 - Co ntro l.Sc hDo c | Drawn By :

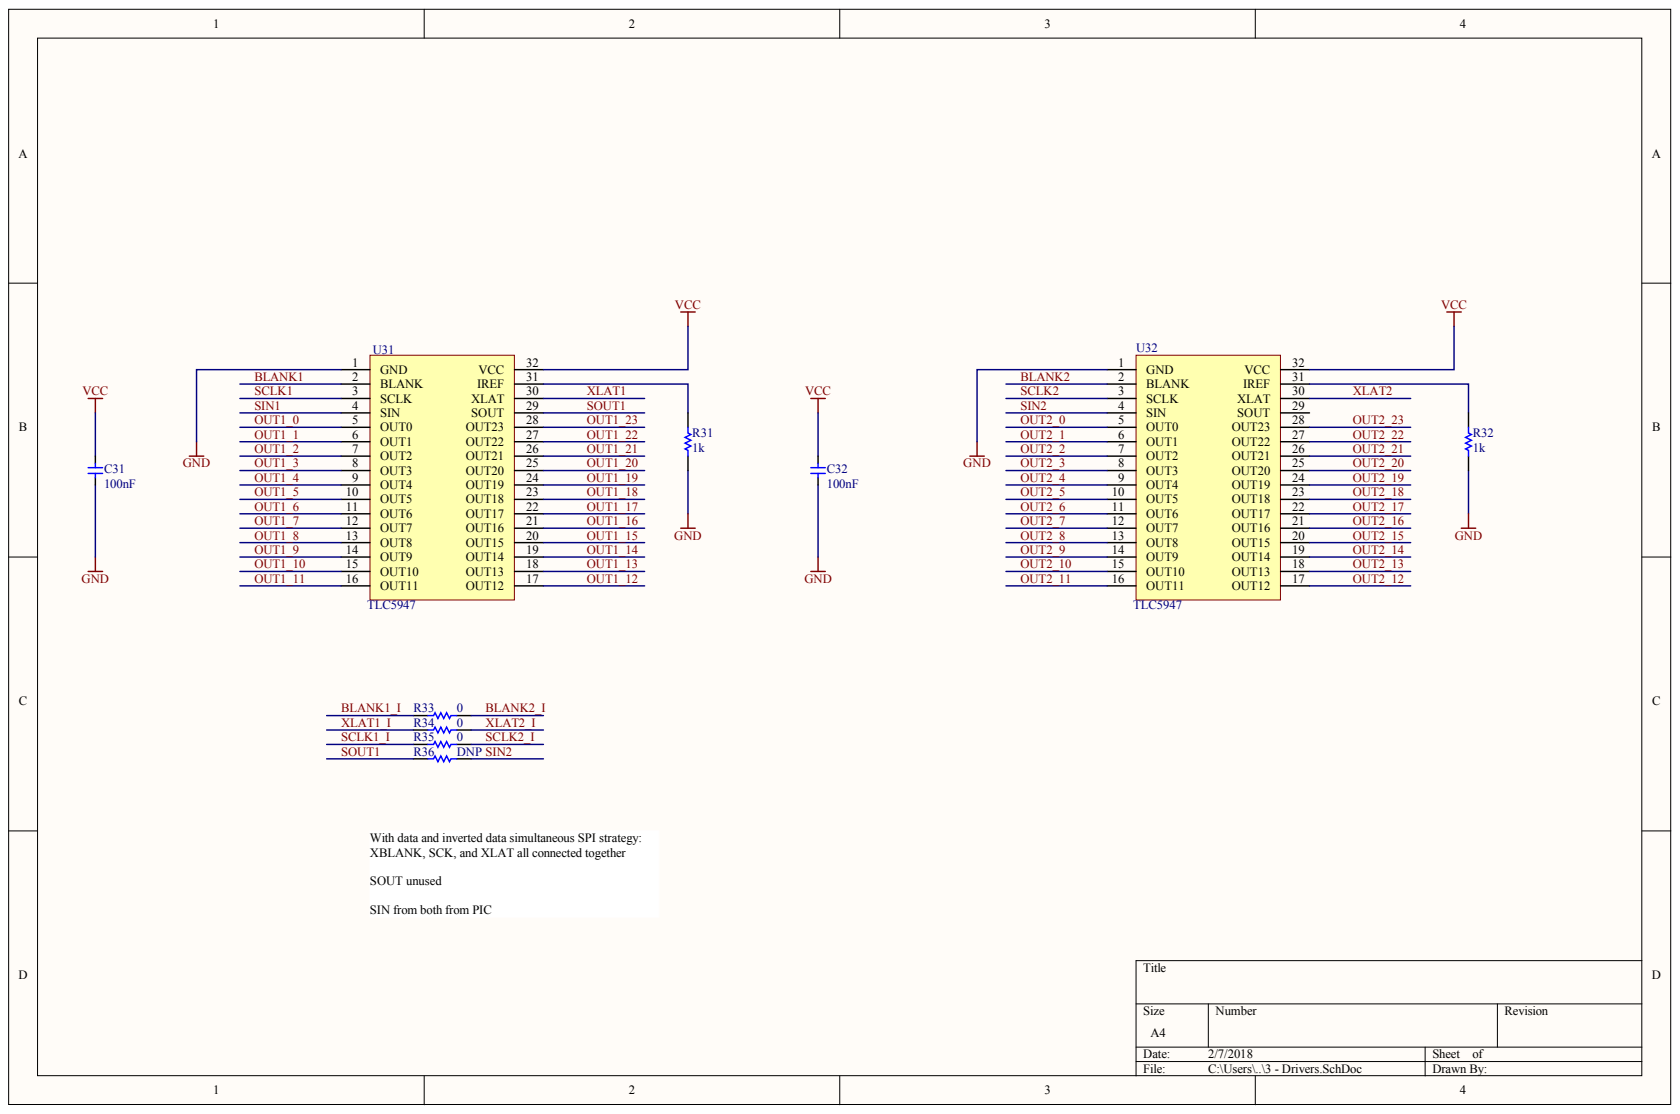
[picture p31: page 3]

Si z e A 4 | Numbe r | Rev isi o n

Date : 2/7/2018 | Sh eet o f
Fi l e : C:\Users\..\3 - Dri v ers.Sc hDo c | Drawn By :

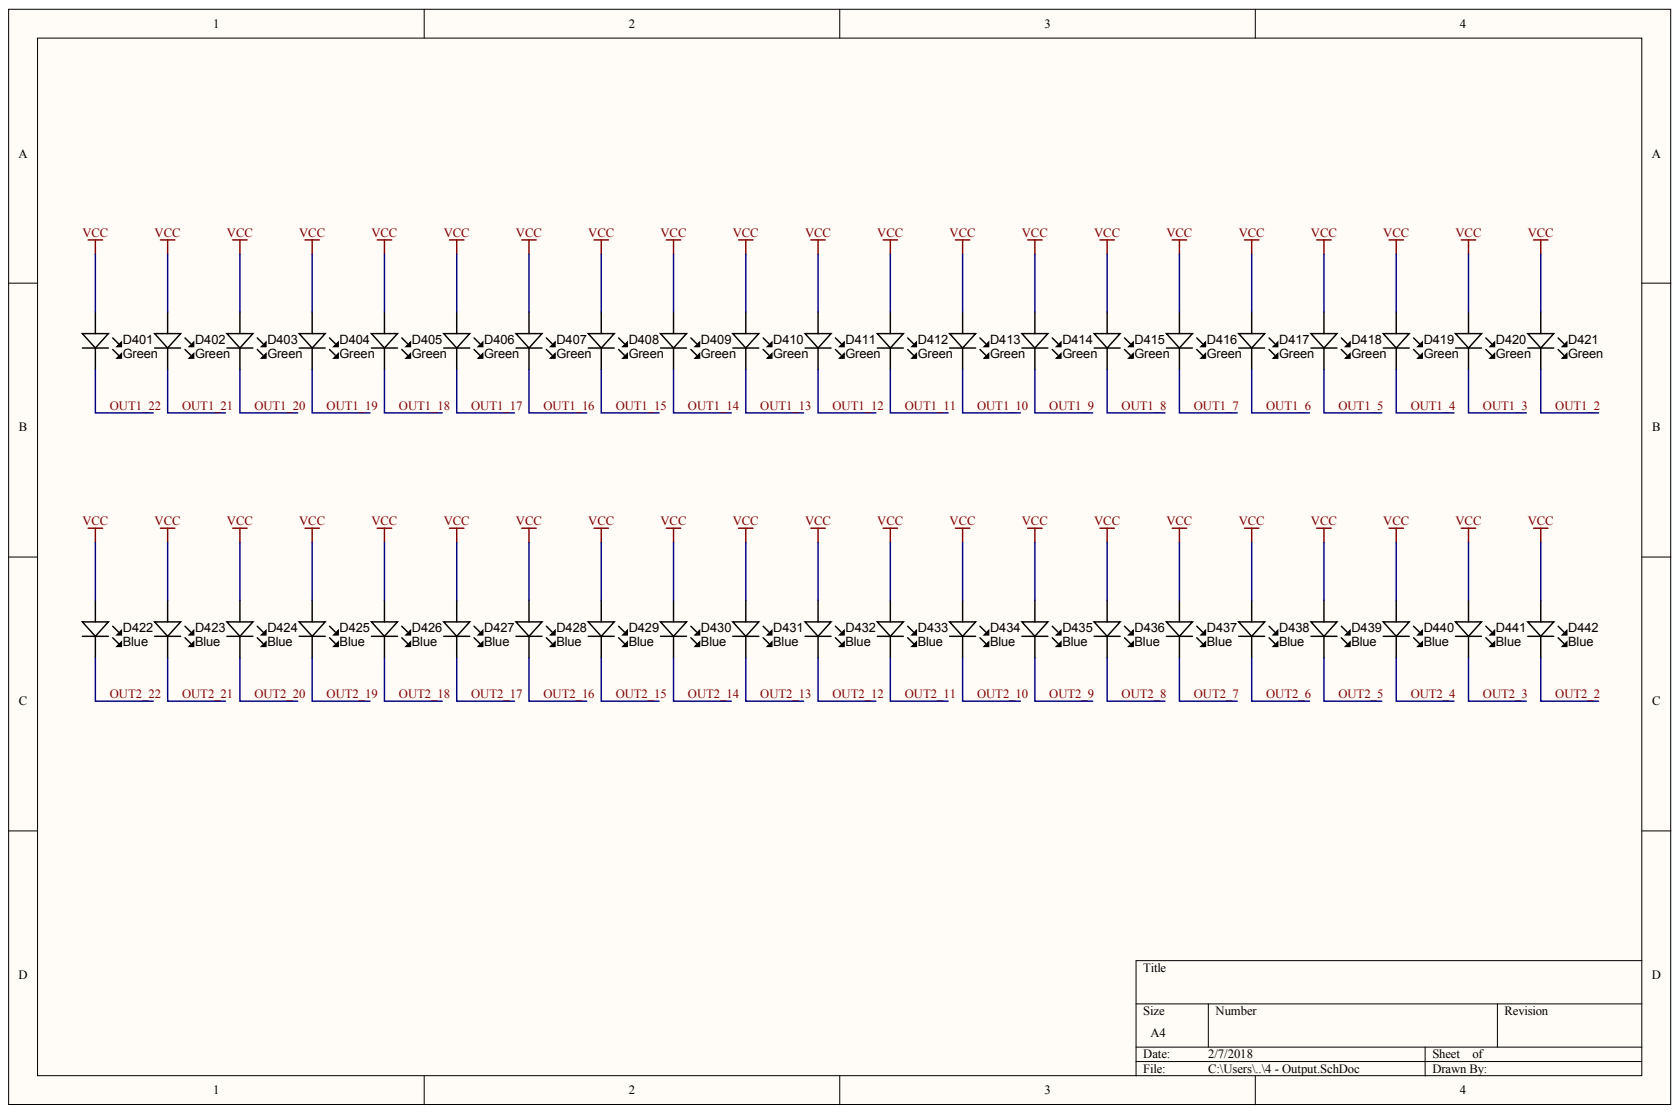
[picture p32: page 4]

Size A4 | Number | Revision

Date: 2/7/2018 | Sheet of
File: C:\Users\..\4 - Output.SchDoc | Drawn By:

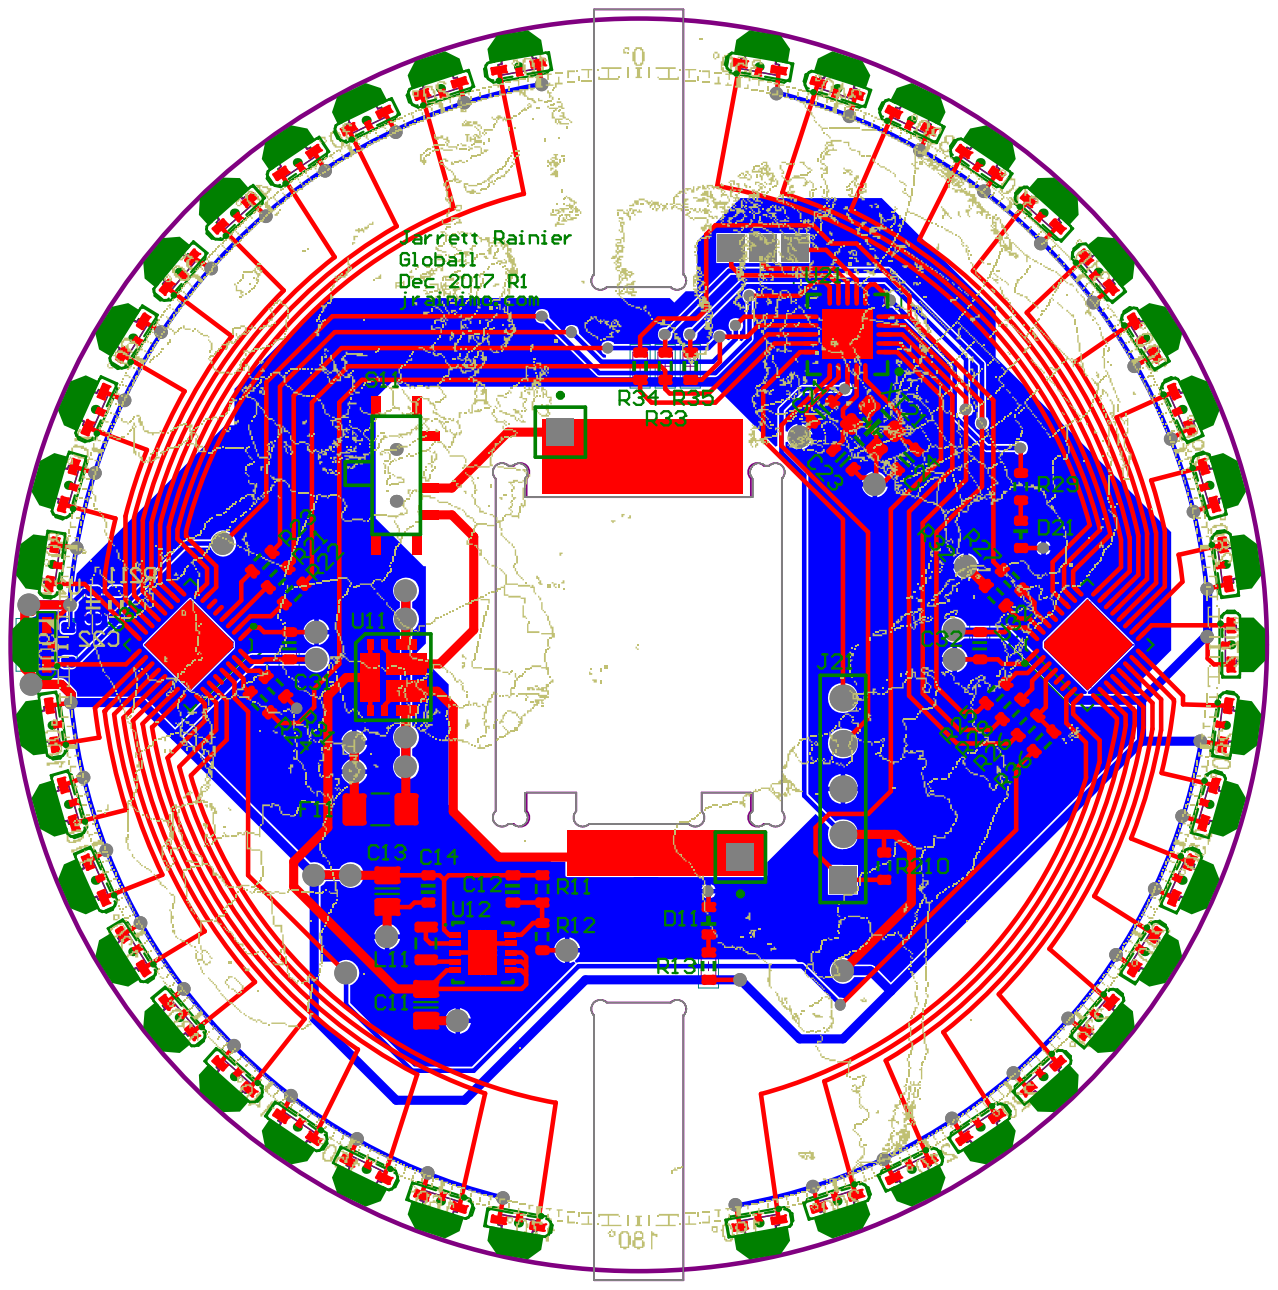
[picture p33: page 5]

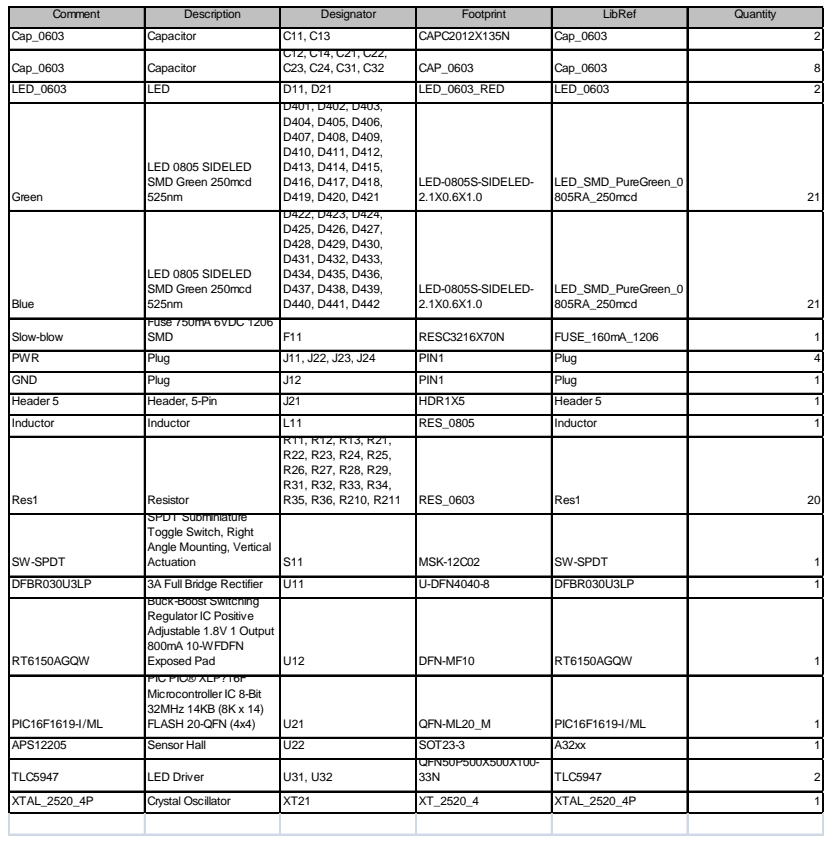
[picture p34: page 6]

Comment | Description | Designator | Footprint | LibRef | Quantity

Cap_0603 | Capacitor | C11, C13 | CAPC2012X135N | Cap_0603 | 2
Cap_0603 | Capacitor | C12, C14, C21, C22, C23, C24, C31, C32 | CAP_0603 | Cap_0603 | 8

LED_0603 | LED | D11, D21 | LED_0603_RED | LED_0603 | 2
Green | LED 0805 SIDELED SMD Green 250mcd 525nm | D401, D402, D403, D404, D405, D406, D407, D408, D409, D410, D411, D412, D413, D414, D415, D416, D417, D418, D419, D420, D421 | LED-0805S-SIDELED-2.1X0.6X1.0 | LED_SMD_PureGreen_0 805RA_250mcd | 21

Blue | LED 0805 SIDELED SMD Green 250mcd 525nm | D422, D423, D424, D425, D426, D427, D428, D429, D430, D431, D432, D433, D434, D435, D436, D437, D438, D439, D440, D441, D442 | LED-0805S-SIDELED-2.1X0.6X1.0 | LED_SMD_PureGreen_0 805RA_250mcd | 21

Slow-blow | Fuse 750mA 6VDC 1206 SMD | F11 | RESC3216X70N | FUSE_160mA_1206 | 1

PWR | Plug | J11, J22, J23, J24 | PIN1 | Plug | 4
GND | Plug | J12 | PIN1 | Plug | 1
Header 5 | Header, 5-Pin | J21 | HDR1X5 | Header 5 | 1
Inductor | Inductor | L11 | RES_0805 | Inductor | 1
Res1 | Resistor | R11, R12, R13, R21, R22, R23, R24, R25, R26, R27, R28, R29, R31, R32, R33, R34, R35, R36, R210, R211 | RES_0603 | Res1 | 20

SW-SPDT | SPDT Subminiature Toggle Switch, Right Angle Mounting, Vertical Actuation | S11 | MSK-12C02 | SW-SPDT | 1

DFBR030U3LP | 3A Full Bridge Rectifier | U11 | U-DFN4040-8 | DFBR030U3LP | 1
RT6150AGQW | Buck-Boost Switching Regulator IC Positive Adjustable 1.8V 1 Output 800mA 10-WFDFN Exposed Pad | U12 | DFN-MF10 | RT6150AGQW | 1

PIC16F1619-I/ML | PIC PIC® XLP? 16F Microcontroller IC 8-Bit 32MHz 14KB (8K x 14) FLASH 20-QFN (4x4) | U21 | QFN-ML20_M | PIC16F1619-I/ML | 1

APS12205 | Sensor Hall | U22 | SOT23-3 | A32xx | 1
TLC5947 | LED Driver | U31, U32 | QFN50P500X500X100-33N | TLC5947 | 2

XTAL_2520_4P | Crystal Oscillator | XT21 | XT_2520_4 | XTAL_2520_4P | 1

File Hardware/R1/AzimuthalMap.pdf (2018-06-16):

# Azimuthal Map

## Center: 20°0'0"N 29°59'59"W Radius: 9000 km


Courtesy of Tom (NS6T)

Map from http://ns6t.net/

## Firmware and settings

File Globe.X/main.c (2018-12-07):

/******************************************************************************/
/* Files to Include                                                           */
/******************************************************************************/

#if defined(__XC)
    #include <xc.h>        /* XC8 General Include File */
#elif defined(HI_TECH_C)
    #include <htc.h>       /* HiTech General Include File */
#elif defined(__18CXX)
    #include <p18cxxx.h>   /* C18 General Include File */
#endif

#if defined(__XC) || defined(HI_TECH_C)

#include <stdint.h>        /* For uint8_t definition */
#include <stdbool.h>       /* For true/false definition */

#endif

#include "mcc_generated_files/mcc.h" 
#include "user.h" 
#include "gamma.h"
#include "../tools/blue.h"
#include "../tools/green.h"


/******************************************************************************/
/* User Global Variable Declaration                                           */
/******************************************************************************/

/* i.e. uint8_t <variable_name>; */

/******************************************************************************/
/* Main Program                                                               */
/******************************************************************************/

void main(void)
{
    /* Configure the oscillator for the device */
    //ConfigureOscillator();

    /* Initialize I/O and Peripherals for application */
    //InitApp();
    SYSTEM_Initialize();

    unsigned int i;
    uint16_t delayTimer = 0;
    uint8_t testLed = 0;    
    unsigned int frame;
    uint8_t mapInc = 5;    
    
    //BLANK1_SetHigh();
    XLAT1_SetLow();
    
    
    uint8_t blob[TABLESIZE];
    
    //Zero out buffer
    for(i = 0; i < TABLESIZE; i++) {
        blob[i] = 0x00;
    }

    frame = 0;
    angleInt = 0;
    
    AT_ResolutionSet(HPIXELS - 1);
    
    EnableInterrupts();
    //DisableInterrupts();
    
    for(i = 0; i < VPIXELS; i++) {
        setChannel(blob, i, 0xFFFF);
    }
    LEDMap(blob);
    
    while(1)
    {
        //Green LED mirrors HEF sensor for alignment with magnets
        //LEDs display a test pattern
        if(!AT_IsMeasurementValid()) {
            //DisableInterrupts();
            
            //Magnet calibration mode
            LED1_LAT = HEF_GetValue();
            
            delayTimer++;
            
            if(delayTimer >= 0xFFF) {
                for(i = 0; i <= VPIXELS; i++) {
                    //x =  (blueMap[frame][i] << 4) & blueMap[frame][i];
                    //setChannel(blob, i, blueMap[frame][i]);
                    
                    if (testLed < VPIXELS) {
                        setChannel(blob, i, 0);
                        setChannel(blob, testLed, 0xFFF);
                    } else {
                        setChannel(blob, i, 0xFFF);
                        setChannel(blob, testLed - VPIXELS, 0);
                    }
                    //setChannel(blob, 23 - i, greenMap[frame][i]);
                }
                LEDMap(blob);
                testLed = ++testLed % ((VPIXELS * 2) + 1);
                delayTimer = 0xFFFF;
            }
            
        } else {
            LED1_SetLow();
            //EnableInterrupts();
        
            if (frame != angleInt && angleInt < HPIXELS) {
                //frame = (frame + 1 ) % HPIXELS;
                frame = angleInt;

                DisableInterrupts();
                for(i = 0; i < VPIXELS; i++) {
                    //x =  (blueMap[frame][i] << 4) & blueMap[frame][i];
                    setChannel(blob, i, blueMap[frame][i]);
                    //setChannel(blob, 23 - i, greenMap[frame][i]);
                }
                LEDMap(blob);
                EnableInterrupts();
                //__delay_ms(100);
            }
        }
        
    }

}

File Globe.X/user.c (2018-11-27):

/******************************************************************************/
/* Files to Include                                                           */
/******************************************************************************/

#if defined(__XC)
    #include <xc.h>         /* XC8 General Include File */
#elif defined(HI_TECH_C)
    #include <htc.h>        /* HiTech General Include File */
#elif defined(__18CXX)
    #include <p18cxxx.h>    /* C18 General Include File */
#endif

#if defined(__XC) || defined(HI_TECH_C)

#include <stdint.h>         /* For uint8_t definition */
#include <stdbool.h>        /* For true/false definition */

#endif

#include "user.h"



/******************************************************************************/
/* User Functions                                                             */
/******************************************************************************/
void setChannel(uint8_t *blob, uint8_t channel, uint16_t value) {
    uint8_t lvalue;
    uint8_t rvalue;
    uint8_t newVal;
    uint8_t byteAddr;
    
    if(channel % 2 == 0) {
        byteAddr = (channel * 3) >> 1;
        lvalue = (uint8_t)(value & 0xFF);
        rvalue = (uint8_t)(value >> 8);
        
        *(blob + byteAddr) = lvalue;
        newVal = (*(blob + byteAddr + 1)) & 0xF0;
        newVal = rvalue | newVal;
        
        *(blob + byteAddr + 1) = newVal;
    } else { //channel % 2 == 1
        byteAddr = (((channel - 1) * 3) >> 1) + 1;
        
        lvalue = (uint8_t)(value << 4) & 0xF0;
        rvalue = (uint8_t)(value >> 4);
        
        newVal = (*(blob + byteAddr)) & 0x0F;
        newVal = lvalue | newVal;
        
        *(blob + byteAddr) = newVal;
        *(blob + byteAddr + 1) = rvalue;
    }
}

void LEDMap(uint8_t *blob)
{
    uint8_t data = 0;
    
    XLAT1_SetLow();
    
    for(int i = TABLESIZE - 1; i >= 0; i--) {
        data = *(blob + i);
        SPIWrite(data);
        //SPIWrite(0xFF & i);
    }
    
    XLAT1_SetHigh();
    __delay_us(1);
    XLAT1_SetLow();
}

void LEDSingle(uint8_t address)
{
    uint8_t data = 0;
    
    XLAT1_SetLow();
    
    for(int i = TABLESIZE - 1; i >= 0; i--) {
        if(i == address) {
            SPIWrite(0x00);
        } else {
            SPIWrite(0xFF);
        }
    }
    
    XLAT1_SetHigh();
    __delay_ms(10);
    XLAT1_SetLow();
}

void SPIWrite(uint8_t data)
{
    
    // Send
    //SSPBUF = data;
    
    // Wait
    //while(!SSP1STATbits.BF);
    SPI_Exchange8bit(data);
}

inline void EnableInterrupts(void) {
    INTCONbits.GIE = 1;
    INTCONbits.PEIE = 1;
}

inline void DisableInterrupts(void) {
    INTCONbits.GIE = 0;
    INTCONbits.PEIE = 0;
}

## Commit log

2017-11-04 Initial commit with TLC5947 driver
2017-11-15 Gen cleanup and bash script with current prod settings
2017-11-23 Angular Timer initial driver - very sloppy
    [main.c, user.c]
2017-11-28 Angular timer tweaks, set clock to 32MHz
2018-06-16 Added original hardware files as submitted
    [1 - Power.SchDoc, 2 - Control.SchDoc, 3 - Drivers.SchDoc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]
2018-06-16 Schematic output too
2018-06-28 Test patterns on test points working
    [out.csv]
2018-11-19 Added R2 hardware files
    [1 - Power.SchDoc, 2 - Control.SchDoc, 3 - Drivers.SchDoc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]
2018-11-23 Fixed spurious LED turn-ons
    [main.c]
2018-11-27 Added mechanicals
    [1 - Base Support.dxf, 1 - Magnet Holder.dxf, 1 - Main Plate.dxf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]
2018-11-28 Current project status
2019-04-17 Started R2 mechanicals
    [1 - Base Support.dxf, 1 - Magnet Holder.dxf, 1 - Main Plate.dxf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]
